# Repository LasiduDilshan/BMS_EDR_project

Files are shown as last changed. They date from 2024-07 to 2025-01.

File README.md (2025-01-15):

video1
---
Photographic_Evidence_EBMS 1-03
Photographic_Evidence_EBMS 1-04
Photographic_Evidence_EBMS 1-05
Photographic_Evidence_EBMS 1-06
Photographic_Evidence_EBMS 1-07
Photographic_Evidence_EBMS 1-08
Photographic_Evidence_EBMS 1-09
Photographic_Evidence_EBMS 1-10
Photographic_Evidence_EBMS 1-11
Photographic_Evidence_EBMS 1-12
Photographic_Evidence_EBMS 1-13
Photographic_Evidence_EBMS 1-14
Photographic_Evidence_EBMS 1-15
Photographic_Evidence_EBMS 1-16
Photographic_Evidence_EBMS 1-17
Photographic_Evidence_EBMS 1-18
Photographic_Evidence_EBMS 1-19
Path

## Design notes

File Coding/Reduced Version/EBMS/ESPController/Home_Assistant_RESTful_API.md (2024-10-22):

# EBMS v4
## Home Assistant RESTful API integration

### Secrets Configuration YAML file for Home Assistant
```
# Use this file to store secrets like usernames and passwords.
# Learn more at https://www.home-assistant.io/docs/configuration/secrets/

Ebms_api_token: XXXXXXXXXXXXXXXXXXXXXXXX
```

### Example Configuration YAML file for Home Assistant
```
# Example configuration.yaml entry for Home Assistant integration with EBMS

rest:
  - resource: http://192.168.0.70/ha
    scan_interval: 10
    timeout: 5
    method: "GET"
    headers:
      Content-Type: application/json
      ApiKey: !secret Ebms_api_token
    sensor:
      - unique_id: "Ebms.activerules"
        value_template: "{{ value_json.activerules }}"
        name: "EBMS Active rules"
        state_class: "measurement"

      - unique_id: "Ebms.chargemode"
        value_template: "{{ value_json.chgmode }}"
        name: "EBMS Charge mode"
        state_class: "measurement"

      - unique_id: "Ebms.lowest_bank_voltage"
        value_template: "{{ value_json.lowbankv }}"
        name: "EBMS Lowest bank voltage"
        unit_of_measurement: "mV"
        device_class: "voltage"

      - unique_id: "Ebms.highest_bank_voltage"
        value_template: "{{ value_json.highbankv }}"
        name: "EBMS Highest bank voltage"
        unit_of_measurement: "mV"
        device_class: "voltage"

      - unique_id: "Ebms.lowest_cell_voltage"
        value_template: "{{ value_json.lowcellv }}"
        name: "EBMS Lowest cell voltage"
        unit_of_measurement: "mV"
        device_class: "voltage"

      - unique_id: "Ebms.highest_cell_voltage"
        value_template: "{{ value_json.highcellv }}"
        name: "EBMS Highest cell voltage"
        unit_of_measurement: "mV"
        device_class: "voltage"

      - unique_id: "Ebms.highest_external_temp"
        value_template: "{{ value_json.highextt }}"
        name: "EBMS Highest cell temperature"
        unit_of_measurement: "°C"
        device_class: "temperature"

      - unique_id: "Ebms.highest_internal_temp"
        value_template: "{{ value_json.highintt }}"
        name: "EBMS Highest passive balance temperature"
        unit_of_measurement: "°C"
        device_class: "temperature"

      - unique_id: "Ebms.current"
        value_template: "{% if 'c' in value_json %}{{ value_json.c }}{% else %}0{% endif %}"
        name: "EBMS DC Current"
        unit_of_measurement: "A"
        device_class: "current"
        icon: "mdi:current-dc"

      - unique_id: "Ebms.voltage"
        value_template: "{% if 'v' in value_json %}{{ value_json.v }}{% else %}0{% endif %}"
        name: "EBMS DC voltage"
        unit_of_measurement: "V"
        device_class: "voltage"

      - unique_id: "Ebms.power"
        value_template: "{% if 'pwr' in value_json %}{{ value_json.pwr }}{% else %}0{% endif %}"
        name: "EBMS Battery power"
        unit_of_measurement: "W"
        device_class: "power"

      - unique_id: "Ebms.stateofcharge"
        value_template: "{% if 'soc' in value_json %}{{ value_json.soc }}{% else %}0{% endif %}"
        name: "EBMS State of charge"
        unit_of_measurement: "%"
        device_class: "battery"

      - unique_id: "Ebms.dynamic_charge_voltage"
        value_template: "{% if 'dyncv' in value_json %}{{ value_json.dyncv }}{% else %}0{% endif %}"
        name: "EBMS Dynamic charge voltage"
        unit_of_measurement: "V"
        device_class: "voltage"

      - unique_id: "Ebms.dynamic_charge_current"
        value_template: "{% if 'dyncc' in value_json %}{{ value_json.dyncc }}{% else %}0{% endif %}"
        name: "EBMS Dynamic charge current"
        unit_of_measurement: "A"
        device_class: "current"

    binary_sensor:
      - unique_id: "Ebms.charge_allowed"
        value_template: "{{ value_json.chgallow }}"
        name: "EBMS Battery charging allowed"

      - unique_id: "Ebms.discharge_allowed"
        value_template: "{{ value_json.dischgallow }}"
        name: "EBMS Battery discharging allowed"
```

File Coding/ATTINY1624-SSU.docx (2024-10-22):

## ADC: 12-bit

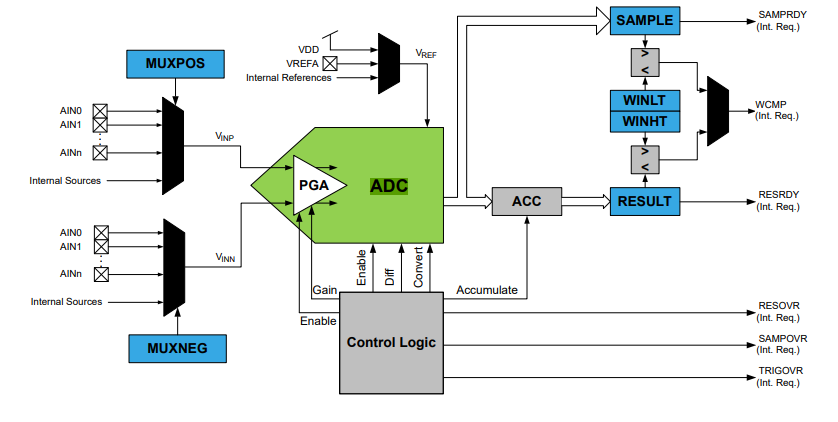
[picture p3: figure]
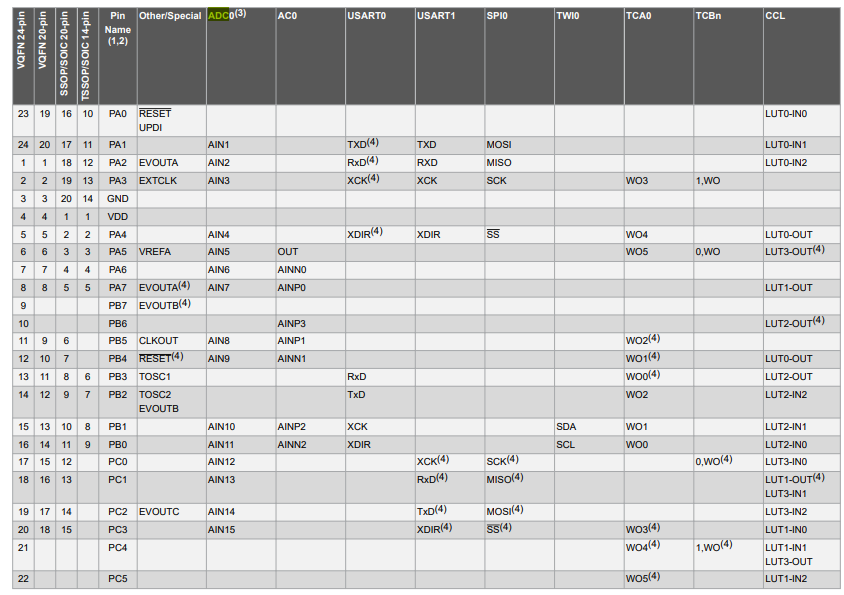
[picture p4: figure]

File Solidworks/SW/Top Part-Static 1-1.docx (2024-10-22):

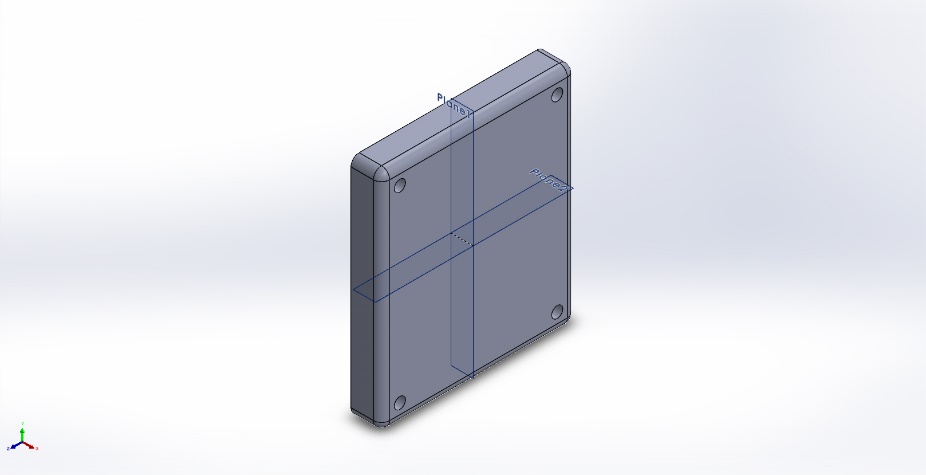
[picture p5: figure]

Simulation of Top Part

Date: Monday, May 13, 2024
Designer: Solidworks

Study name: Static 1

Analysis type: Static
Description No Data

# Assumptions

# Model Information

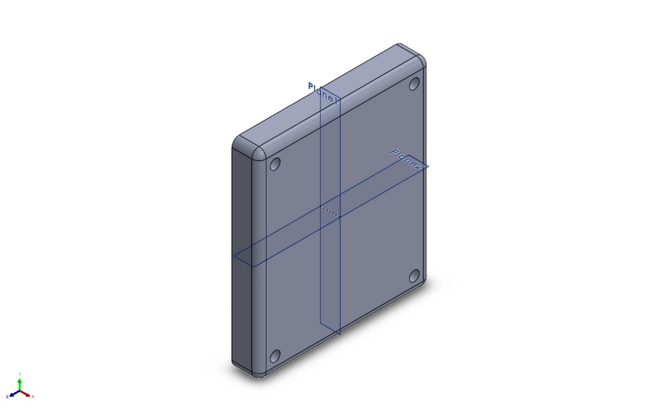
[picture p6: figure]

Model name: Top Part

Current Configuration: Default

Solid Bodies
Document Name and Reference | Treated As | Volumetric Properties | Document Path/Date Modified

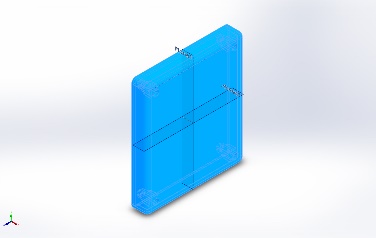
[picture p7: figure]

Mirror2 | Solid Body | Mass:4.41933e-05 kg Volume:4.41933e-05 m^3 Density:1 kg/m^3 Weight:0.000433094 N | C:\Users\senum\OneDrive\Desktop\New folder (6)\EDR\SW\Top Part.SLDPRT May 13 14:14:10 2024

# Study Properties

Study name | Static 1
Analysis type | Static
Mesh type | Solid Mesh
Thermal Effect: | On
Thermal option | Include temperature loads
Zero strain temperature | 298 Kelvin
Include fluid pressure effects from SOLIDWORKS Flow Simulation | Off
Solver type | FFEPlus
Inplane Effect: | Off
Soft Spring: | Off
Inertial Relief: | Off
Incompatible bonding options | Automatic
Large displacement | Off
Compute free body forces | On
Friction | Off
Use Adaptive Method: | Off
Result folder | SOLIDWORKS document (C:\Users\senum\OneDrive\Desktop\New folder (6)\EDR\SW)

# Units

Unit system: | SI (MKS)
Length/Displacement | mm
Temperature | Kelvin
Angular velocity | Rad/sec
Pressure/Stress | N/m^2

# Material Properties

No Data

# Loads and Fixtures

No Data

# Connector Definitions

No Data

# Contact Information

No Data

# Mesh information

No Data

# Sensor Details

No Data

# Resultant Forces

No Data

No Data

# Beams

No Data

# Study Results

No Data

# Conclusion

Analyzed with SOLIDWORKS Simulation Simulation of Top Part 16

Analyzed with SOLIDWORKS Simulation Simulation of Top Part 1

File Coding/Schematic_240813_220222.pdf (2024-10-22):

1 | 2 | 3 | 4 | 5 | 6 | 7 | 8
1 | 2 | 3 | 4 | 5 | 6 | 7 | 8

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
F Date: 2023-01-03 KiCad E.D.A. eeschema 5.1.9+dfsg1-1+deb11u1 Size: A3 | Rev: 4.6

## Id: 1/1 Title: DIYBMS ESP32 CONTROLLER

File: ControllerCircuit.sch Sheet: / Stuart Pittaway

C10
1uF

+3V3 +5V GND

C5

# 22uF GND

+3V3 10K R²⁹

R25
220R
1
2 | 3

4 U12 AQY282SX

+3.3V R²⁰ ¹M

1
2
3
4
J12 ScrewTerminal | R24

22K

R21

220R | GND GND

1
2
3
4
J7ScrewTerminal | 10K | R¹⁹ R² 2K²
1

2 3 Q4 AO3400A

GND

R1
220R

C8

100nF | C¹¹ | 1uF 51K R²⁷ | R28

22K

C9

100nF | GND
SW1 SW_Push | C⁷ | 1uF R⁷ 51K | R26
22K

+3.3V

3V3

1

IO26

10

IO27

11

IO14

12

IO12

13 GND1

14

IO13

15 SD2

16 SD3

17 CMD

18 EXT_5V

19 EN

2 GND3 20

IO23 21

IO22 22 | TXD0 23 | RXD0 24
IO21 25 | GND2 26

IO19 27

IO18 28

IO5 29 | SENSOR_VP

3

IO17 30

IO16 31

IO4 32

IO0 33

IO2 34

IO15 35 | SD1 36 | SD0 37 | CLK 38 | SENSOR_VN

4

IO34

5

IO35

6

IO32

7

IO33

8

IO25

9 U4 ESP32-DEVKITC-32D GND

+3.3V

B2 1 GND

# 2 VCCA

3 A2 4 A1 5 OE 6 VCCB

# 7 B1 8 U1 TXS0102DCU

TXD 1 | GND

## 2 VCC

3 RXD 4 VREF 5 CANL 6 CANH 7 S

8 | U7 SN65HVD1050D

1
2
3
4
5
6
7

J14 Unused header

3
1

2 D8 NUP2105LT1G

GND R⁹ | 120R | GND

1 2 JP4

OptTermination | C6

100nF

1

2 3 Q2AO3400A

1
2
3

J3 ScrewTerminal3Pin R14

560R 51K | R¹⁵ ⁵⁶⁰R | R¹³ D⁴ YELLOW LED | 1

2
3
4

# J4 ScrewTerminal

T_IRQ 1 | D/C 10 | RESET 11 | CS 12 | GND 13 | VCC | 14 T_DO 2 | T_DIN 3 | T_CS 4 | T_CLK 5 | MISO 6
LED 7 | SCK 8 | MOSI 9 | SD_SCK SD1 SD_MISO SD2 SD_MOSI SD3 SD_CS SD4

LCD1

LCD

R4
560R

R5
2K2 R16
2K2 | D5

LL4148

1

2 TX1 Transmit R3
180R

1

2 RX1 Receive

1

2 | 3 4 U2 EL3H7(B)(TA)-G

R8

120R

1
2

J10 Conn_01x02_Female

R17
220R

1
2
3

J2ScrewTerminal3Pin

1

2 | 3

4 U9 AQY282SX R18
220R

D2
LL4148

R6
120R

2 1

JP1 OptTermination

MISO VCC | 1

2 SCK 3 MOSI 4 RST 5 GND

6

J8

2x3 2.54mm IDC Connectors

+5V GND

BG

1 R

2

3 | 4
| 5

6 RGB D1

1
2
3
4

J1ScrewTerminal R

1 | RE 2 | DE 3 | D
4 | GND | 5 A

6 B

7 VCC 8 U5 SN65HVD75DR

C1

100nF | C2

# 100nF K1 SRD-05VDC-SL-C

SW2 SW_Push

1

2 3 Q1AO3400A R10

560R 51K | R¹¹ ⁵⁶⁰R | R¹² D³ YELLOW LED

C3
22uF 6.3V | C4

22uF 6.3V GND

1 VO 2 VI 3 U6 AMS1117-3.3 F1 Fuse, 1.85A

K2 SRD-05VDC-SL-C

+3V3 | GND

# +3V3 GND

C12

0.1uF-100V R30
10R

R23
10R
CS 1 Vin+ 10 | MOSI 2 Alert 3 MISO 4 SCLK 5 VS

## 6 GND

# 7 Vbus 8 Vin- 9 U8

INA229

1

2

J5 ScrewTerminal | +3.3V | GND GND | GND

1

3 | 2 Q3 AO3401A GND | GND
+3V3 | GND | GND ¹⁰K | R³¹ +3V3 GND | 10K | R³² | GND

+3V3 GND

GND

GND C¹⁴ | 100nF | GND C¹³¹uF

GND

1

2

3

4

# J9Shunt GND GND

+3.3V GND

BG

R
1

2

3

4 D6 MHPC3528CRGBCT | P10 | 13 P11 | 14 P12 | 15 P13 | 16 P14 | 17 P15 | 18 P16 | 19 P17 | 20
INT 1 | P6 | 10 P7 | 11 GND 12 VCCI 2 ADDR 21 | SCL 22 | SDA 23 | VCCP ²⁴ RESET 3 | P0 | 4 P1 | 5 P2 | 6 P3 | 7 P4 | 8 P5 | 9 U3 TCA6416APWR | GND

+3V3

+3V3 | GND
+3V3 GND | GND
GND | 10K | R²²
GND

PWR_FLAG FUSED⁵V FUSED⁵V

FUSED5V

FUSED5V

FUSED5V

FUSED5V

FUSED5V

FUSED5V

FUSED5V | FUSED⁵V

FUSED5V FUSED⁵V FUSED⁵V

FUSED5V

FUSED5V

SHUNT_CS

IO15

IO34_INPUT | VSPI_CLK

EXT_IO_A

IO0_BOOT

IO17 EXT_IO_C

EXT_IO_B

EXT_IO_A TCA⁶⁴¹⁶A_INTB

VSPI_MOSI SD_CS

TOUCH_CS

TOUCH_IRQ

RELAY4_SSR

RELAY2 RELAY1

VSPI_MISO

IO16 VSPI_MOSI VSPI_MOSI | VSPI_MISO

VSPI_MISO

VSPI_MISO

VSPI_CLK

VSPI_CLK

VSPI_CLK

VSPI_MOSI

ESP3V3 CANBUS_TX RELAY1

IO36_INPUT RESET RESET DISPLAY_DC

DISPLAY_CS CANBUS_RX RS485_ENABLE

IO39_INPUT RS485_RX | HSPI_CLK HSPI_MOSI HSPI_MISO

VSPI_CLK

VSPI_MISO
VSPI_MOSI AVRISP_RESET | SW1EXT
IO2 RELAY2 | RESET

SHUNT_IRQ

IO4

IO5

# SW1EXT SW2EXT

IO34_INPUT SW2EXT

IO26
IO25
IO33
IO32
IO35_INPUT
IO34_INPUT EXT_IO_D

RED_LED

RED_LED

SW1OUTPUT

SHUNT_CS

TCA6416A_INTB

SHUNT_IRQ

IO21
IO22

IO22

IO21 RESET | EXT_IO_D
MODULE_TX1 MODULE_RX1 | EXT_IO_C

EXT_IO_B

SW2OUTPUT BLUE_LED

DISPLAY_LED

RELAY4_SSR

SW2OUTPUT

HSPI_MOSI HSPI_MISO

VSPI_CLK

VSPI_MOSI SD_CS

SW1OUTPUT

VSPI_MISO

HSPI_CLK
IO27 BLUE_LED

i2c_SDA

i2c_SCK

i2c_SCK
i2c_SDA

i2c_SDA

IO34_INPUT

IO5 MODULE_RX1

i2c_SCK

IO0_BOOT CANBUS_TX

IO26 TOUCH_IRQ

IO17

IO16 MODULE_TX1 IO32 RS485_TX RS485_TX

IO33 SD_CS RS485_ENABLE RS485_RX

IO35_INPUT

IO39_INPUT CANBUS_RX

IO36_INPUT

TOUCH_CS

IO2 GREEN_LED | GREEN_LED

IO25 DISPLAY_DC

IO4

IO27 RELAY3_SSR

DISPLAY_CS | RELAY3_SSR

IO15 DISPLAY_LED

AVRISP_RESET | Connected to USB port
ILI9341 | MICRO SD CARD
Standard Module comms | The pins GPIO16 and GPIO17 are available for use only on the boards with

the modules ESP32-WROOM and ESP32-SOLO-1. The boards with ESP32-WROVER modules have the pins reserved for internal use.

Emergency stop button
(pulled high)

120R optional resistor
for CAN termination, CONNECTED by default Green/Red intentionally

swapped to match component + ground! (foot print wrong)

IO34 used on previous controller versions as TCA9534A_INTERRUPT_PIN Non-Commercial You may not use the material for commercial purposes.

# BATTERY+ LCSC C²⁹⁶²⁰⁹⁶

This work is licensed under a Creative Commons Attribution-NonCommercial-ShareAlike 2.0 UK: England & Wales License.

https://creativecommons.org/licenses/by-nc-sa/2.0/uk/ You are free to: Share copy and redistribute the material in any medium or format

Adapt remix, transform, and build upon the material
The licensor cannot revoke these freedoms as long as you follow the license terms.

Reverse polarity protection

CHARGER/LOAD

1=USB SERIAL
3=USB SERIAL
6=N/A
7=N/A
8=N/A
9=[NOT AVAILABE ON DEVKIT] mapped to IO16 on DEVKIT 10=[NOT AVAILABE ON DEVKIT] mapped to IO17 on DEVKIT 11=N/A
12=DISPLAY HSPI MISO / MTDI/GPIO12: internal pull-down 13=DISPLAY HSPI MOSI 14=DISPLAY HSPI CLK

16=SEE IO9
17=SEE IO10
18= VSPI_CLK (CONFIRMED)
19= VSPI_MISO (CONFIRMED) 20=N/A

23=VSPI_MOSI (CONFIRMED) 24 = N/A

28 = N/A
29 = N/A
30 = N/A
31 = N/A
37 = NOT AVAILABE ON DEVKIT 38 = NOT AVAILABE ON DEVKIT

Flyback diode calc Relay, 5VDC = 72mA 70ohm+/-10% 0.36W

LL4148, Peak Reverse Voltage 100V
Peak Fwd Surge Current 0.5A @1s, 1A@1ms Power Dissipation 500mW

120R optional resistor

for termination, CONNECTED by default Consider using part C8387 WJ15EDGRC-3.81-2P Pluggable System Terminal Block 3.81mm Power input

ONBOARD CURRENT SHUNT/MONITOR

Using 4 pin connector
to reduce part count

VBUS

i2c pull up resistors
RS-485

## CANBUS

PIN 1 is an output (received data). RS485 half duplex IC required.

LCD SCREEN = 42mA (including backlight @ 2.5mA)

## POWER CONSUMPTION

Display is only item on bus so no CS needed

Provides 5V I/O pins for external interfaces and relays, up to 10mA per port.

i2c address 0x21 (ADDR is high) | Push buttons with de-bounce

Panasonic AQY282SX

Solid State Relay 60V 500mA AC or DC | PIN MAPPING

Changes:

CANBUS_S has been removed, hard wired to low LED output resistor values changed to cater for 5v

ESP32 Strapping Pins
GPIO0, GPIO5 and GPIO15 have pull-up resistors enabled during power up.
GPIO2 and GPIO12 have pull-down resistors enabled during power up.
These pull-up and pull-down resistors can be disabled via software once the device is running.

The ESP32 will enter the serial bootloader when GPIO0 is held low on reset. Otherwise it will run the program in flash.

GPIO0 has an internal pullup resistor, so if it is left unconnected then it will pull high.

Many boards use a button marked BOOT that pulls GPIO0 low when pressed.

GPIO2 must also be either left unconnected/floating, or driven Low, in order to enter the serial bootloader. VSPI CLK=IO18 VSPI MISO=IO19 VSPI MOSI=IO23 HSPI CLK=IO14 HSPI MISO=IO12 HSPI MOSI=IO13 RESET/EN line is held high by resistor on ESP32 module/board DUAL FOOT PRINT - ONLY FIT 1 LED!

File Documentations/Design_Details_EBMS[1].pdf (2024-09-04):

EN-2160

# Electronic Design Realization

# Expandable Battery Management System

# Design Details

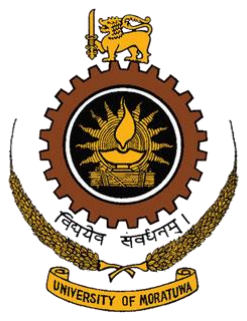
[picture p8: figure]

Name | Index Number
Dilshan N.L. Dodangoda D.K.S.J. Gunawardana W.N.M. Wathudura T.R. | 210129P 210150V 210199D 210682D

## Table of Contents

## Circuit Design Details

## Cell Module

This module is an integral component designed for the real-time monitoring of individual battery cells within a pack, each with a nominal voltage of 3.7V. This module is specifically developed to ensure the optimal performance, safety, and longevity of battery packs used in various applications, ranging from portable electronic devices to electric vehicles. The detailed functionalities, including voltage and temperature monitoring, communication via UART, and protective measures, are outlined below:

### 1. Over-voltage monitoring and voltage balancing circuit:

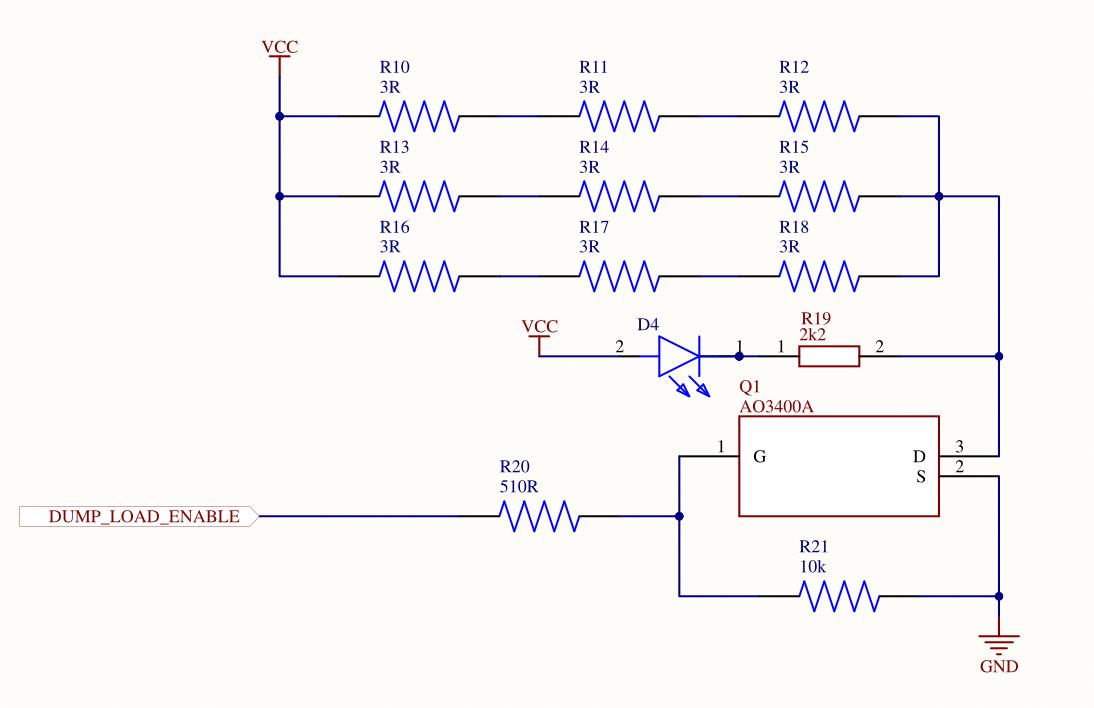
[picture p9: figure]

The battery monitoring system incorporates a sophisticated control strategy to prevent overcharging, which is critical for maintaining battery health and safety. The system utilizes a microcontroller unit (MCU) that continuously monitors the voltage levels of each battery cell within the pack. When the voltage of a cell exceeds the recommended threshold of 3.7V, indicative of potential overcharging, the MCU takes proactive measures to regulate the charge and maintain voltage stability.

❖ Activation of the Dump Load Enabler:
- Upon detection of an over-voltage condition, the MCU activates the Dump Load Enabler, which in turn controls a MOSFET. The MOSFET acts as a switch that reroutes the excess current away from the battery cell.

❖ Current Diversion Through Resistors:
- The redirected current is passed through a predefined set of resistors. These resistors are specifically chosen for their ability to handle the excess current without overheating or damage. By flowing through these resistors, the overcurrent is safely dissipated as heat, and the voltage across the battery cell is effectively lowered and stabilized at the

safe level of 3.7V.

❖ Balancing Charge Across Series-Connected Battery Packs:
- This controlled method of handling overcharge conditions not only protects individual cells but also contributes to the overall balance of charge across series-connected battery packs. By ensuring that no single cell overcharges, the system promotes uniformity in the charge state across the entire battery pack, which is essential for optimal performance and longevity of the batteries.

❖ System Benefits:
- This approach not only prevents the detrimental effects of overcharging, such as potential thermal runaway and reduced battery life but also enhances the reliability and efficiency of the battery management system. By maintaining each cell within its optimal voltage range, the system ensures that the battery pack delivers consistent performance and exhibits extended service life.

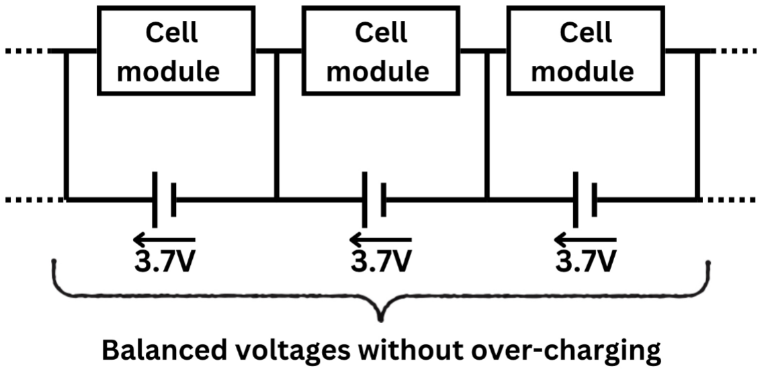
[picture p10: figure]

### 2. Temperature Sensing Circuit:

To ensure optimal performance and safety, the temperature of both the battery and the circuit within the battery management system (BMS) is meticulously monitored. This dual temperature monitoring is achieved using the CMFB103F3950FANT temperature sensor, a highly accurate and reliable component selected for its precision in thermal measurement.

❖ Sensor Specifications and Functionality:

- The CMFB103F3950FANT sensor is utilized for its exceptional responsiveness and stability across a broad range of temperatures. It is designed to provide precise temperature readings, which are critical for preventing thermal runaway and enhancing the longevity of the battery system. The sensor's ability to operate under varying environmental conditions without degradation makes it an ideal choice for the demanding requirements of battery management.

❖ Separate Monitoring of Circuit and Battery Temperatures:

In our system, separate sensors are deployed to measure.

1. The Internal Circuit Temperature: Monitoring the temperature of the electronic circuitry is essential to prevent overheating and potential damage to the BMS components. Elevated temperatures within the circuit can indicate inefficiencies or malfunctions, which may require immediate intervention.
2. The Battery Temperature: Direct measurement of the battery's temperature provides data necessary to effectively manage charging and discharging processes. It helps in maintaining the battery within safe operational limits, thus safeguarding against hazards and prolonging battery life.

Both sets of data are critical for the BMS to execute real-time decisions regarding cooling measures, charge rate adjustments, and load balancing, which are dependent on temperature fluctuations.

❖ Integration into BMS:

- Each CMFB103F3950FANT sensor is integrated into the system architecture via dedicated interfaces that relay temperature data to the central processing unit of the BMS. This integration allows for continuous monitoring and instant feedback, enabling dynamic adjustments to operational parameters in response to temperature changes detected by the sensors.
- This strategic approach to temperature monitoring underscores our commitment to system safety and efficiency, ensuring that all components operate within their thermal thresholds, thereby optimizing the performance and durability of the battery system.

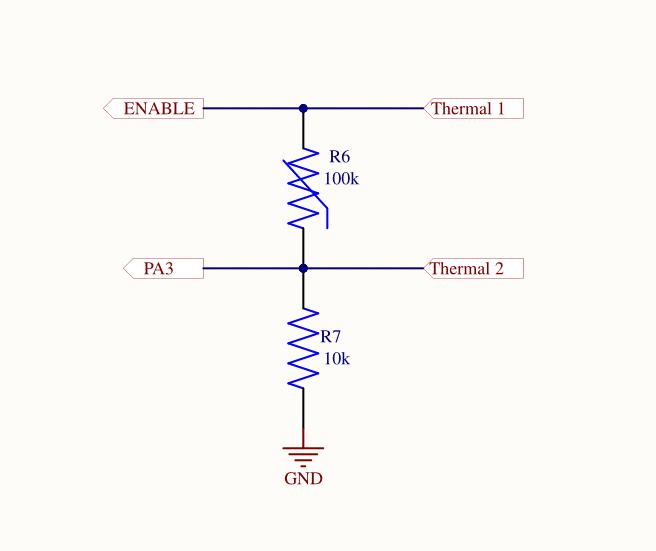
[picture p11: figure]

### 3. Micro-controller Unit:

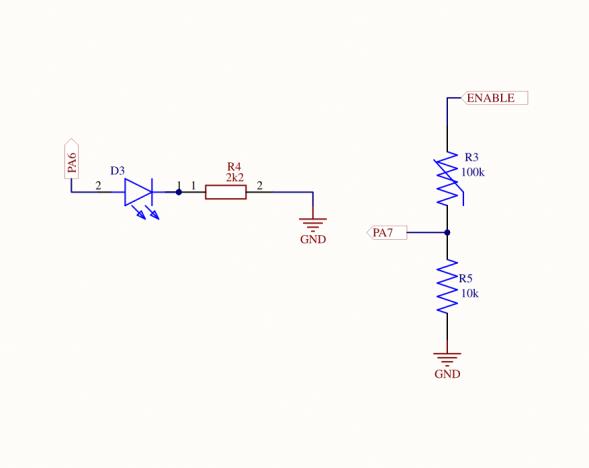
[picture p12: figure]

The battery management system employs a microcontroller to perform critical functions, including the measurement of battery cell voltages and the monitoring of temperatures using connected sensors. The microcontroller used in this system is the ATTINY1624-SSU, selected for its reliability, compact size, and capability to handle multiple inputs efficiently.

❖ Voltage and Temperature Measurement:

- The primary role of the microcontroller within the system is to continuously measure the voltage of each battery cell. This data is vital for assessing the state of charge and overall health of the battery. In parallel, the microcontroller reads inputs from temperature sensors strategically placed to monitor both the internal and ambient temperatures associated with the battery cells. These temperature readings help prevent conditions that could lead to overheating, thereby ensuring safe operation under various load conditions.

❖ Programming the Microcontroller:

- To facilitate precise control over these functions, the ATTINY1624-SSU microcontroller is programmed using a UPDI (Unified Program and Debug Interface) programmer. The UPDI programmer enables efficient uploading of necessary firmware into the microcontroller, which governs its operation. This programming method is advantageous for its simplicity and effectiveness, allowing for easy updates and debugging of the system software.
- The utilization of the UPDI programmer with the ATTINY1624-SSU microcontroller ensures that the system can be finely tuned to respond appropriately to the complex dynamics of battery management. This setup not only guarantees precision in monitoring but also provides flexibility in system configuration to accommodate future enhancements or adjustments in operational protocols.

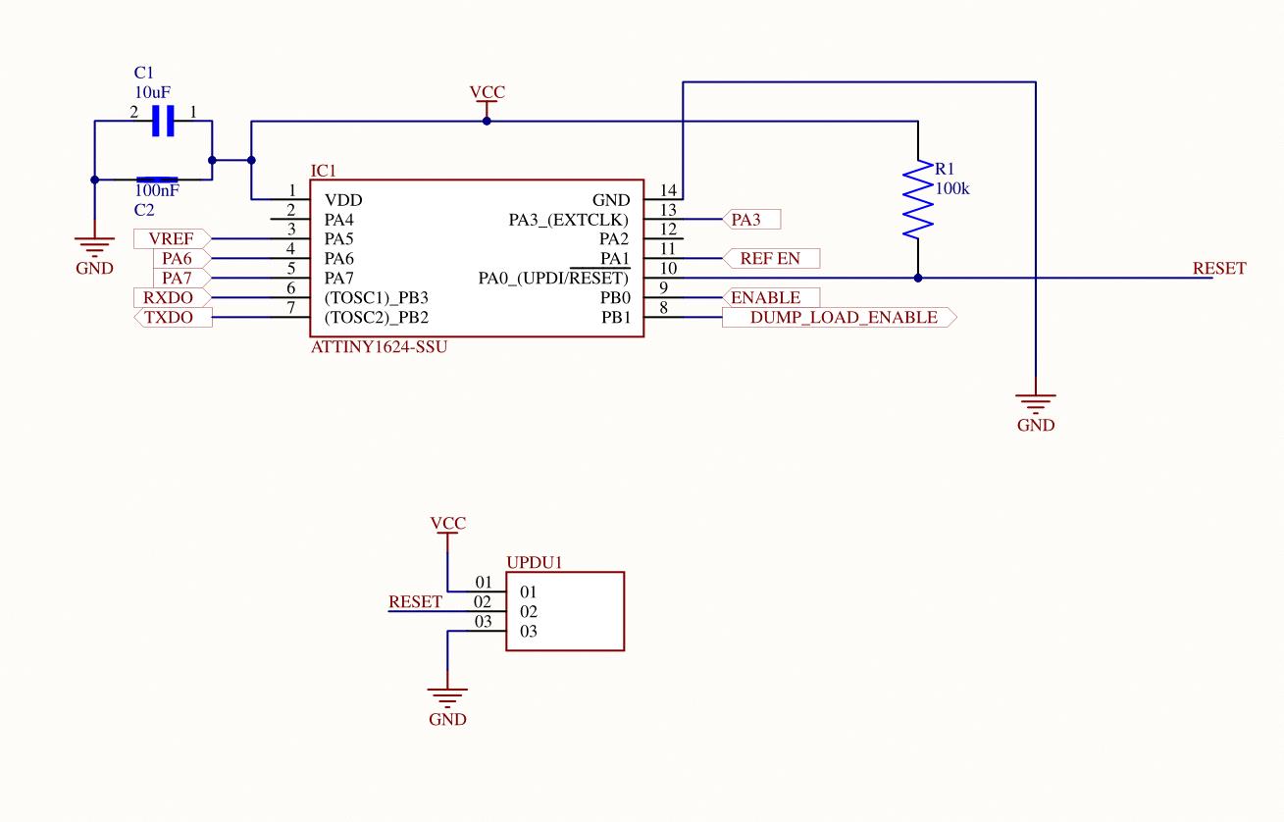
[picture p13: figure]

### 4. UART transmitter and receiver:

In the battery management system (BMS), communication and data interchange between individual battery cell modules and the main controller module are facilitated using the Universal Asynchronous Receiver/Transmitter (UART) protocol. This choice of communication standard is instrumental due to its reliability, simplicity, and effectiveness in systems requiring serial data exchange.

❖ Implementation of UART Communication

- UART protocol is utilized to establish a robust communication link within the BMS. Each battery cell module is equipped with UART capabilities, allowing it to transmit critical data such as voltage levels and temperature readings to the main controller module. This data is essential for real-time monitoring and management of the battery cells, enabling the main controller to make informed decisions regarding charge regulation, health assessment, and fault diagnostics.

❖ Importance of Series Connectivity

- The battery system is designed to be series-expandable, allowing for scalability in energy capacity and voltage levels. In such configurations, maintaining coherent and synchronized operation among multiple serially connected battery cell modules becomes crucial. The interconnection of each module in series via UART ensures seamless data transmission across the system, preserving the integrity and timing of the communicated signals. This setup not only supports the current system architecture but also accommodates future expansions with minimal adjustments.

The strategic implementation of UART interconnectivity thereby enhances the overall efficiency and reliability of the BMS, ensuring that each component within the series-connected array can communicate effectively with the main controller. This capability is vital for maintaining balanced charge cycles, monitoring state-of-health across the battery array and executing coordinated responses to operational anomalies.

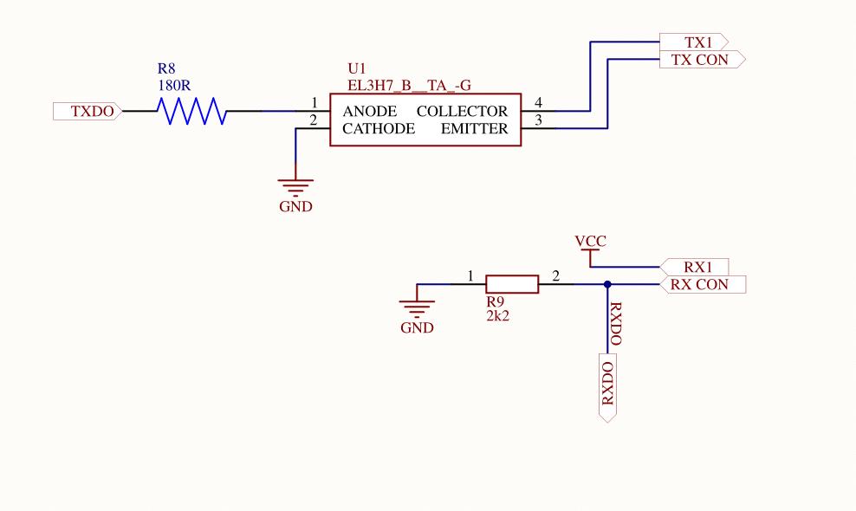
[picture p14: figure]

## Controller Module

### 1. Onboard current shunt monitor

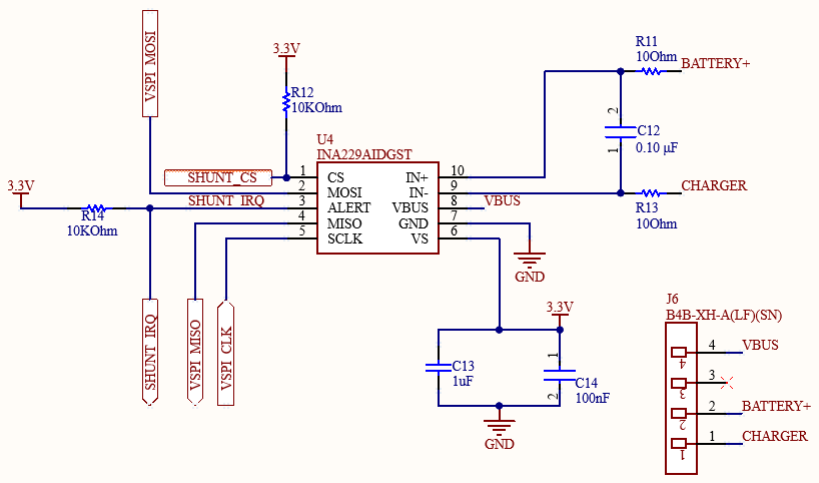
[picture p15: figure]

The onboard current shunt monitor uses the INA219, a high-side current sensor from Texas Instruments.

❖ Circuit Components:

1. INA219 (U4): This is a current shunt and power monitor with an I2C interface.
2. Shunt Resistor (R11): Placed between the load (battery) and the ground to measure the voltage drop caused by the load current.
3. Pull-up Resistors (R12, R13): Connected to the I2C lines to pull them up to 3.3V.
4. Bypass Capacitors (C11, C12, C13, C14): Used to filter noise and stabilize the power supply.
5. Connector (J6): For interfacing with the battery and charger.

❖ Circuit Description:

### 1. Current Measurement:

- The INA219 monitors the current flowing through the shunt resistor (R11).
- The voltage drop across R11 is proportional to the current passing through it.
- INA219 measures this voltage drop and, using the known resistance value of R11, calculates the current using Ohm's Law (I = V/R).

### 2. Power and Bus Voltage Measurement:

- INA219 also measures the bus voltage (VBUS), which is the voltage at the load side of the shunt resistor.
- By measuring both the current and the bus voltage, the INA219 can calculate the power consumed by the load.

### 3. I2C Communication:

- The INA219 communicates with a microcontroller (not shown in the diagram) through the I2C interface.

- The SCL (clock) and SDA (data) lines are connected to the microcontroller’s I2C bus.
- Pull-up resistors (R12, R13) are used to pull these lines up to 3.3V, ensuring proper logic levels for I2C communication.

### 4. Power Supply and Grounding:

- The circuit is powered by a 3.3V supply.
- Bypass capacitors (C11, C12, C13, C14) are placed near the power pins to filter out any high-frequency noise and stabilize the power supply to the INA219 and the I2C bus.

❖ Operation:

- When the system is powered on, the INA219 continuously monitors the voltage drop across the shunt resistor and the bus voltage.
- These measurements are sent to the microcontroller via the I2C interface.
- The microcontroller can then use these readings to monitor the current, voltage, and power consumption of the connected load, which in this case is a battery and charger system.

This circuit is designed to provide real-time monitoring of current and voltage, which is crucial for applications such as battery management systems. By integrating the INA219, the circuit offers precise measurement and easy interfacing with a microcontroller via I2C, making it suitable for the project.

### 2. Reverse polarity protection

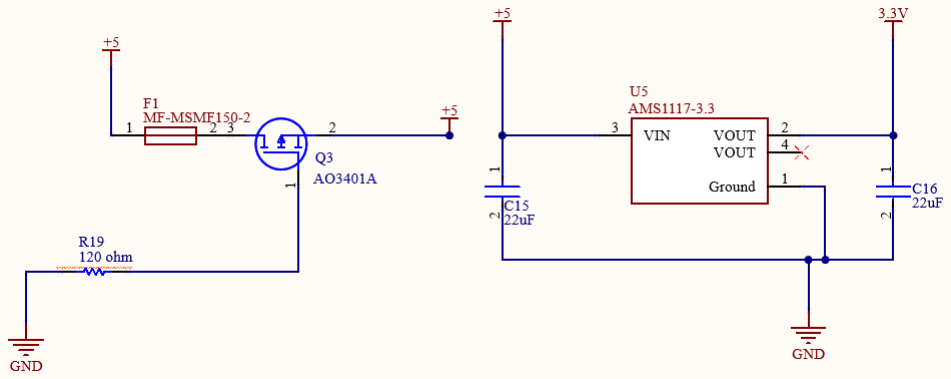
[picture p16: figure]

This circuit is designed to provide reverse polarity protection and voltage regulation for the battery management system

❖ Reverse Polarity Protection:

### 1. MOSFET (Q3 - AO3401A):

- The P-channel MOSFET (Q3) is used for reverse polarity protection.

- When the correct polarity is applied (+5V at the source, ground at the gate through R19):
- The MOSFET turns on, allowing current to flow from the source to the drain, thus providing +5V to the rest of the circuit.
- If the polarity is reversed (ground at the source, +5V at the gate through R19):
- The MOSFET remains off, preventing current from flowing and protecting the circuit from damage.

### 2. Resettable Fuse (F1 - MF-MSMF150-2):

- F1 is a resettable fuse that provides overcurrent protection.
- If the current exceeds the fuse's rating (1.5A), the fuse will trip and open the circuit, preventing damage to the components.
- Once the fault condition is removed, the fuse will reset automatically.

❖ Voltage Regulation:

### 1. Voltage Regulator (U5 - AMS1117-3.3):

- U5 is a linear voltage regulator that converts the +5V input to a stable +3.3V output.
- The VIN pin (pin 3) receives the +5V input.
- The VOUT pin (pin 2) provides the regulated +3.3V output.
- The GND pin (pin 1) is connected to ground.

### 2. Capacitors (C15 and C16 - 22uF):

- C15 and C16 are decoupling capacitors that stabilize the input and output voltages by filtering out noise and providing a smooth voltage supply.
- C15 is connected between the VIN pin and ground.
- C16 is connected between the VOUT pin and ground.

Overall Functionality:

- The circuit ensures that power is only delivered to the battery management system if the input voltage is correctly polarized.
- It protects the system from reverse polarity and overcurrent conditions.
- It provides a stable +3.3V output from a +5V input, suitable for powering components that require a lower voltage.

By incorporating these components, the circuit enhances the reliability and safety of the battery management system.

### 3. IO Expander

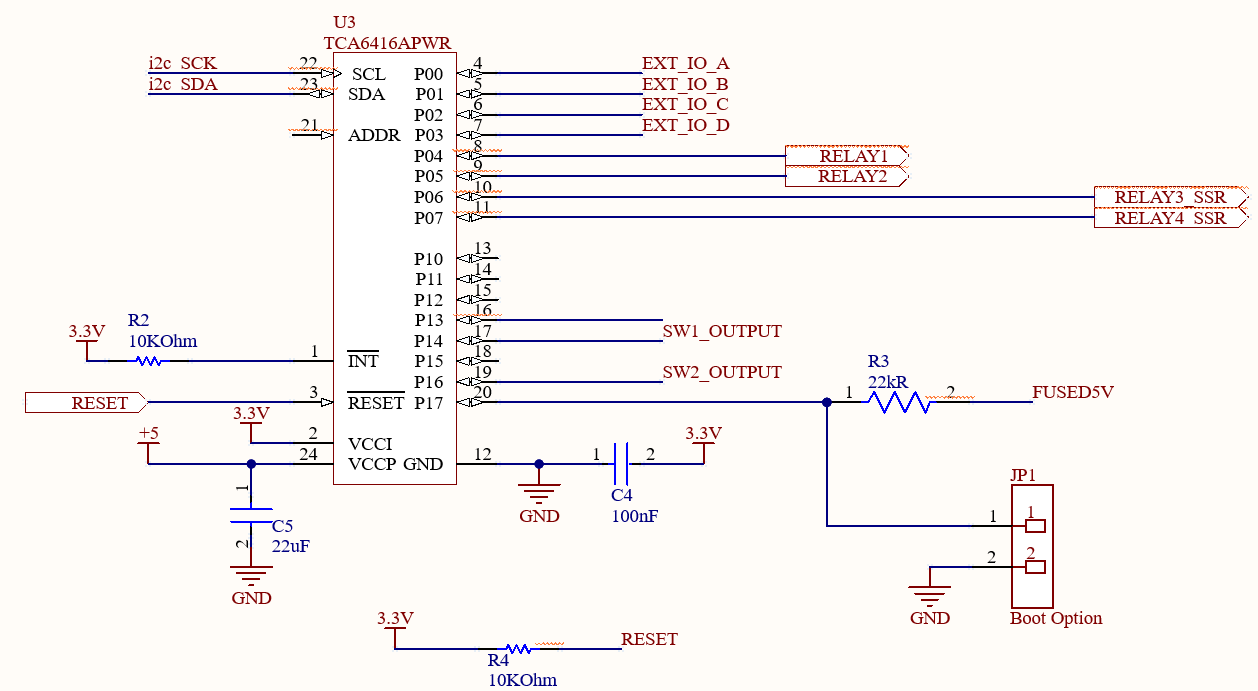
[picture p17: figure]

This schematic illustrates the integration of TCA6416A I/O expander within the battery management system (BMS).

❖ Functional Overview:

### 1. I2C Communication:

- Pins 22 (SCL) and 23 (SDA): These pins facilitate communication with the microcontroller via the I2C bus, allowing the microcontroller to control and monitor the states of the GPIO pins on the I/O expander.

### 2. General Purpose Input/Output (GPIO) Expansion:

- Pins P00 – P17 The TCA6416A provides 16 GPIO pins, which can be configured individually as either inputs or outputs. These pins are connected to various external components:
- EXT_IO_A to EXT_IO_D (Pins 4-7): General-purpose external I/O lines.
- RELAY1 and RELAY2 (Pins 8 and 9): Control signals for mechanical relays, used to switch high power loads or other circuits.
- RELAY3_SSR and RELAY4_SSR (Pins 10 and 11): Control signals for solid-state relays (SSR), offering faster switching and longer life compared to mechanical relays.
- SW1_OUTPUT and SW2_OUTPUT (Pins 18 and 19): Output signals to control or indicate the status of switches, for user inputs or control signals for other devices.

### 3. Power and Ground Connections:

- VCCI (Pin 24): 3.3V supply voltage for the device’s logic.
- VCCP (Pin 2): 5V supply voltage, likely used for driving the external components connected to the GPIOs.
- GND (Pin 1 and others): Common ground reference for the circuit.
- Capacitors:
- C4 (100nF): Provides noise filtering and stabilization for the power supply.
- C5 (22uF): Larger decoupling capacitor to smooth out voltage variations and provide

stable power.

### 4. Control and Configuration:

- RESET (Pin 3): This pin is used to reset the I/O expander. The reset circuit includes a 10kΩ pull-up resistor (R2) and a RESET switch, allowing manual reset of the device.
- INT (Pin 15): The interrupt pin can be used to alert the microcontroller of any changes in the state of the input pins, enabling efficient event-driven programming.

### 5. Boot Option (JP1):

- JP1 Connector: Provides a jumper configuration for boot options, which might be used to select different operational modes or configurations for the system.
- R3 (22kΩ resistor): Pull-up resistor associated with the boot option selection, ensuring a defined logic level when the jumper is not connected.

❖ Overall Functionality:

The TCA6416A I/O expander significantly increases the I/O capacity of the BMS, enabling it to interface with a variety of external components such as relays, switches, and other digital inputs/outputs. This extension of I/O capability allows the BMS to monitor and control more aspects of the battery system, enhancing its functionality and flexibility. Through the I2C interface, the microcontroller can easily manage these additional I/O points, making the system more scalable and adaptable to complex requirements.

### 4. Standard module communication circuit

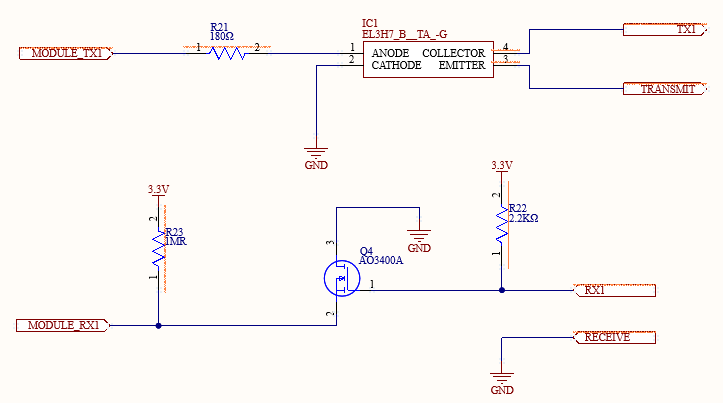
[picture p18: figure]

This schematic illustrates the standard module communication circuit in the BMS. The circuit facilitates the communication between the BMS and external modules, enabling data transmission and reception.

❖ Key Components and Their Functionality:

### 1. Optocoupler (IC1 - EL3H7):

- Pins 1 (Anode) and 2 (Cathode): The input side of the optocoupler, where the signal from the BMS is applied. The optocoupler isolates the transmitting circuit electrically from the receiving circuit.

- Pins 3 (Collector) and 4 (Emitter): The output side of the optocoupler, where the isolated signal is transmitted to the external module.
- Function: The optocoupler provides galvanic isolation, protecting the BMS from voltage spikes and noise that might originate from the external modules. It ensures that the signal integrity is maintained across the isolation barrier.

### 2. Resistors:

- R21 (180Ω): Limits the current through the optocoupler when transmitting data from the BMS (TXI).
- R22 (22kΩ): Pull-down resistor ensuring that the RXI line remains at a known logic level when the transistor is not conducting.
- R23 (1MΩ): Pull-up resistor for the gate of the MOSFET, ensuring it remains off when not driven by the optocoupler.
- Function: These resistors are critical for current limiting, pulling voltages to defined levels, and ensuring stable operation of the circuit components.

### 3. MOSFET (Q4 - AO3400A):

Acts as a switch that is controlled by the optocoupler. When the optocoupler is activated by the BMS transmit signal, the MOSFET allows current to flow, transmitting the signal to the receiving module.

### 4. Communication Lines:

- MODULE TXI: Input from the BMS transmitting module.
- TXI: Transmit line to the external module after passing through the optocoupler.
- MODULE RXI: Input from the receiving module to the BMS.
- RXI: Receive line from the external module, controlled by the MOSFET.
- TRANSMIT and RECEIVE: External connectors for communication with external modules.

This circuit provides a robust and isolated communication interface for the battery management system, ensuring safe and reliable data exchange between the BMS and external modules. The use of an optocoupler ensures electrical isolation, protecting the BMS from potential electrical disturbances, while the MOSFET facilitates controlled signal reception. The resistors ensure proper current flow and voltage levels for stable operation.

## Enclosure Design Details

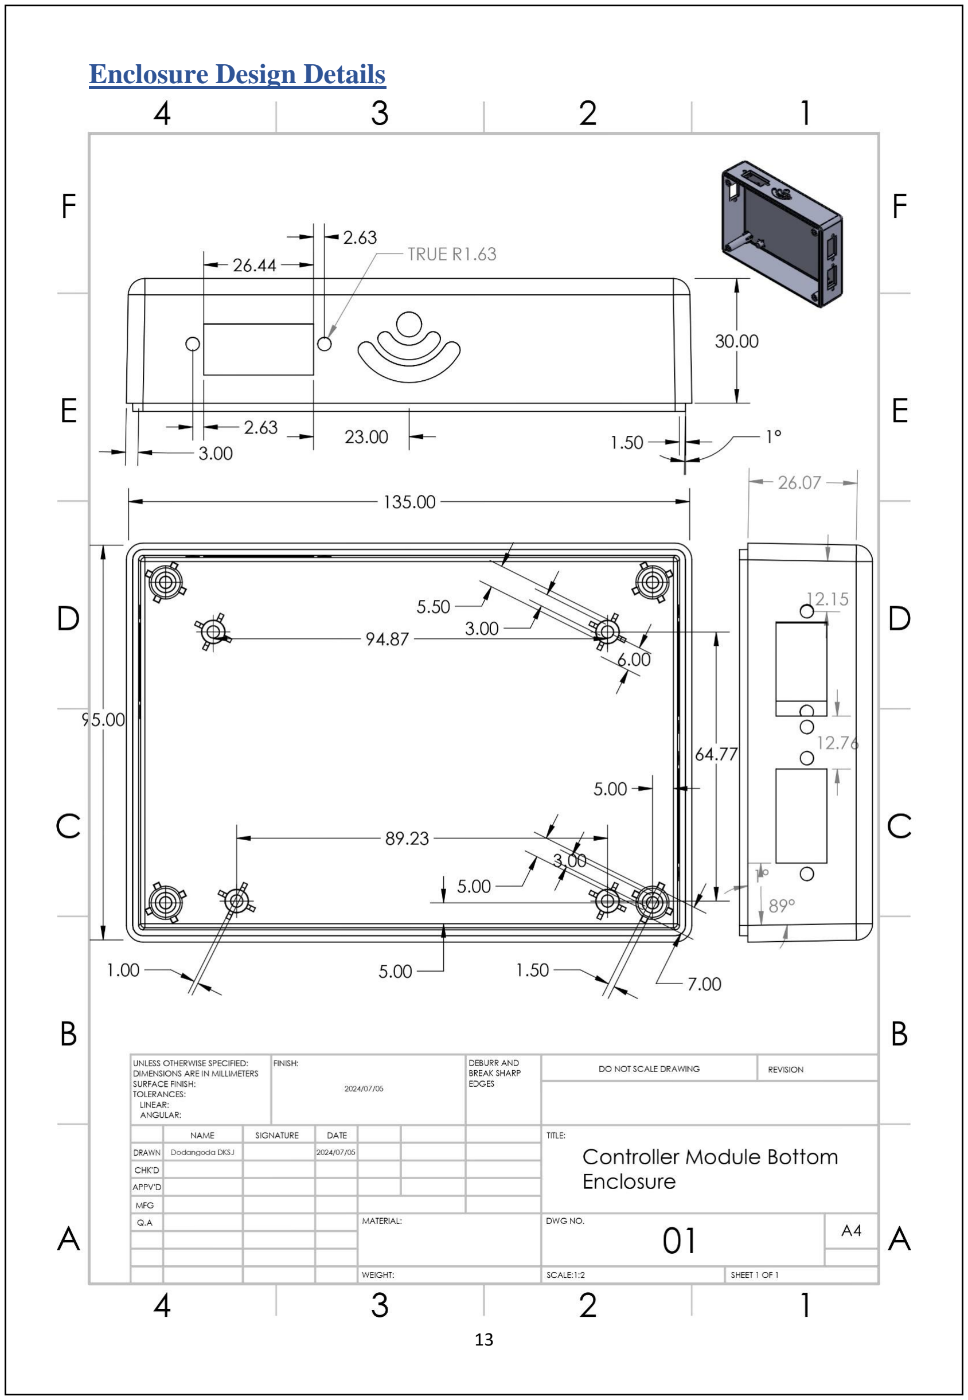
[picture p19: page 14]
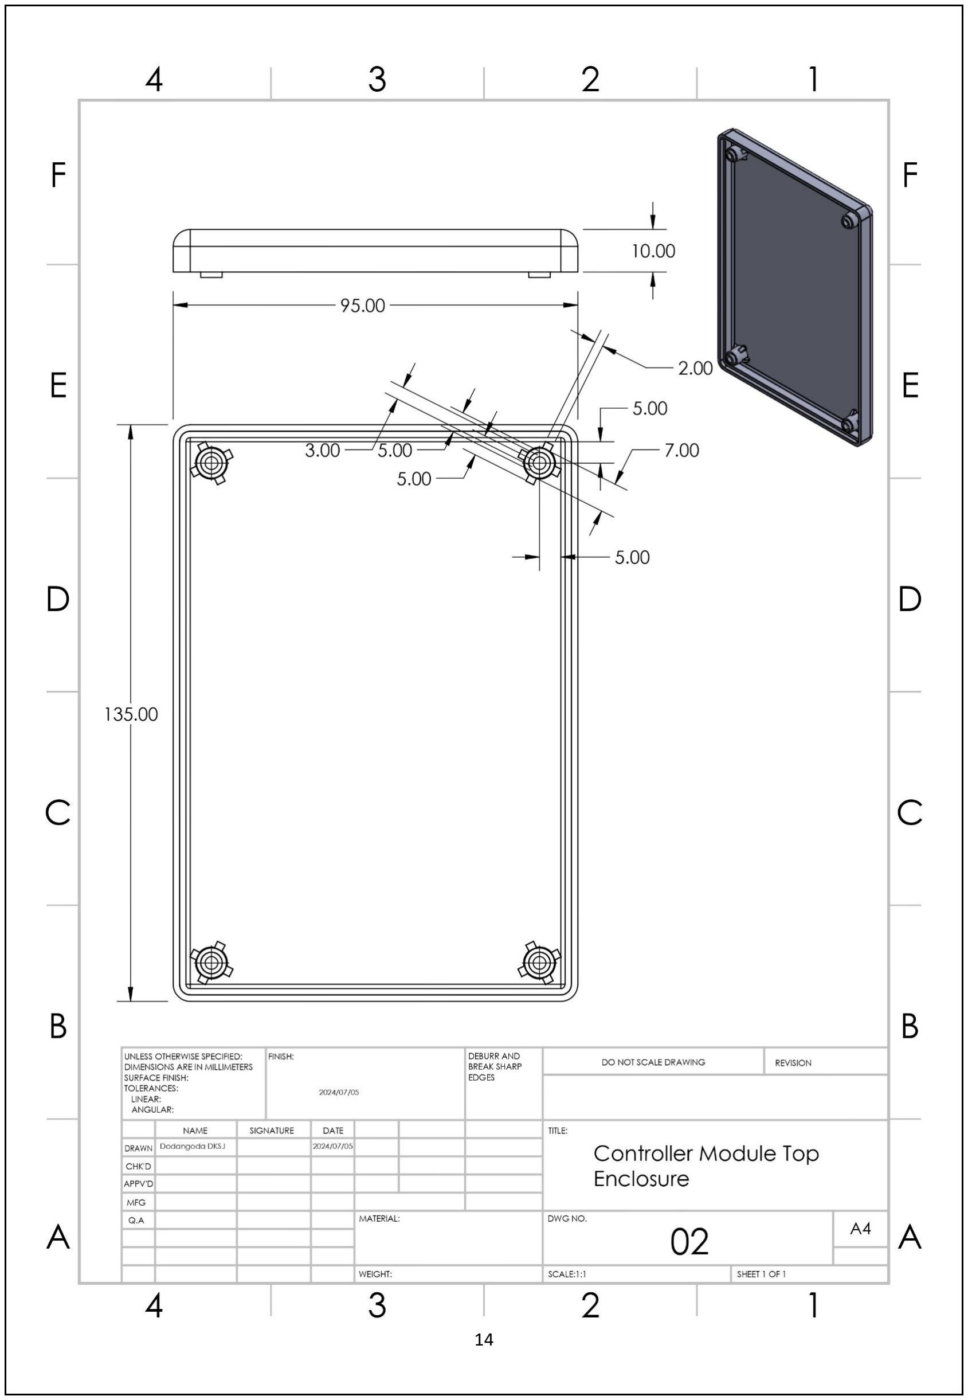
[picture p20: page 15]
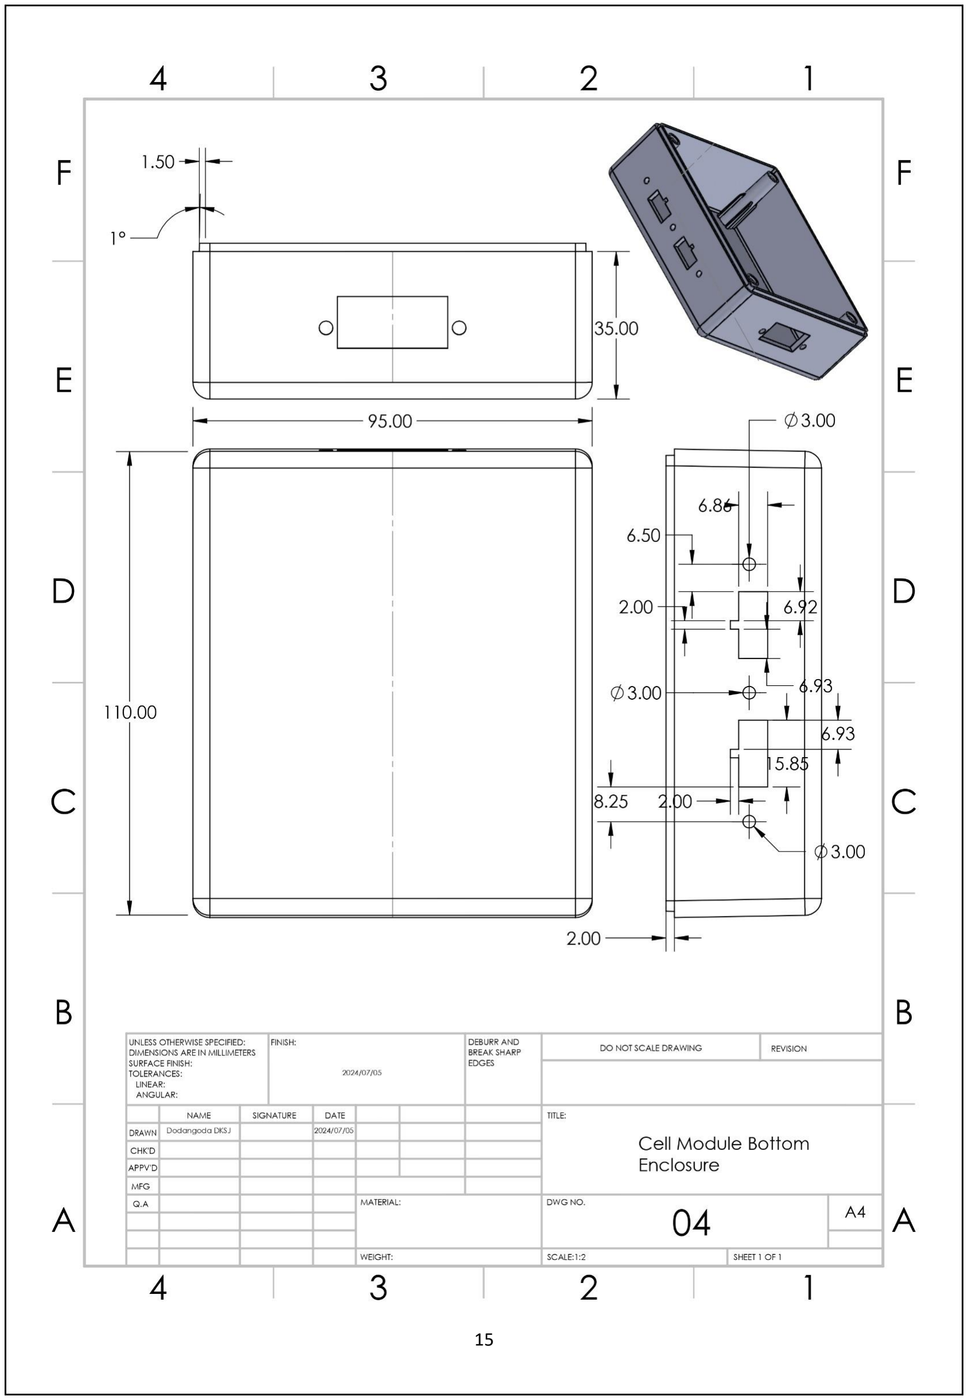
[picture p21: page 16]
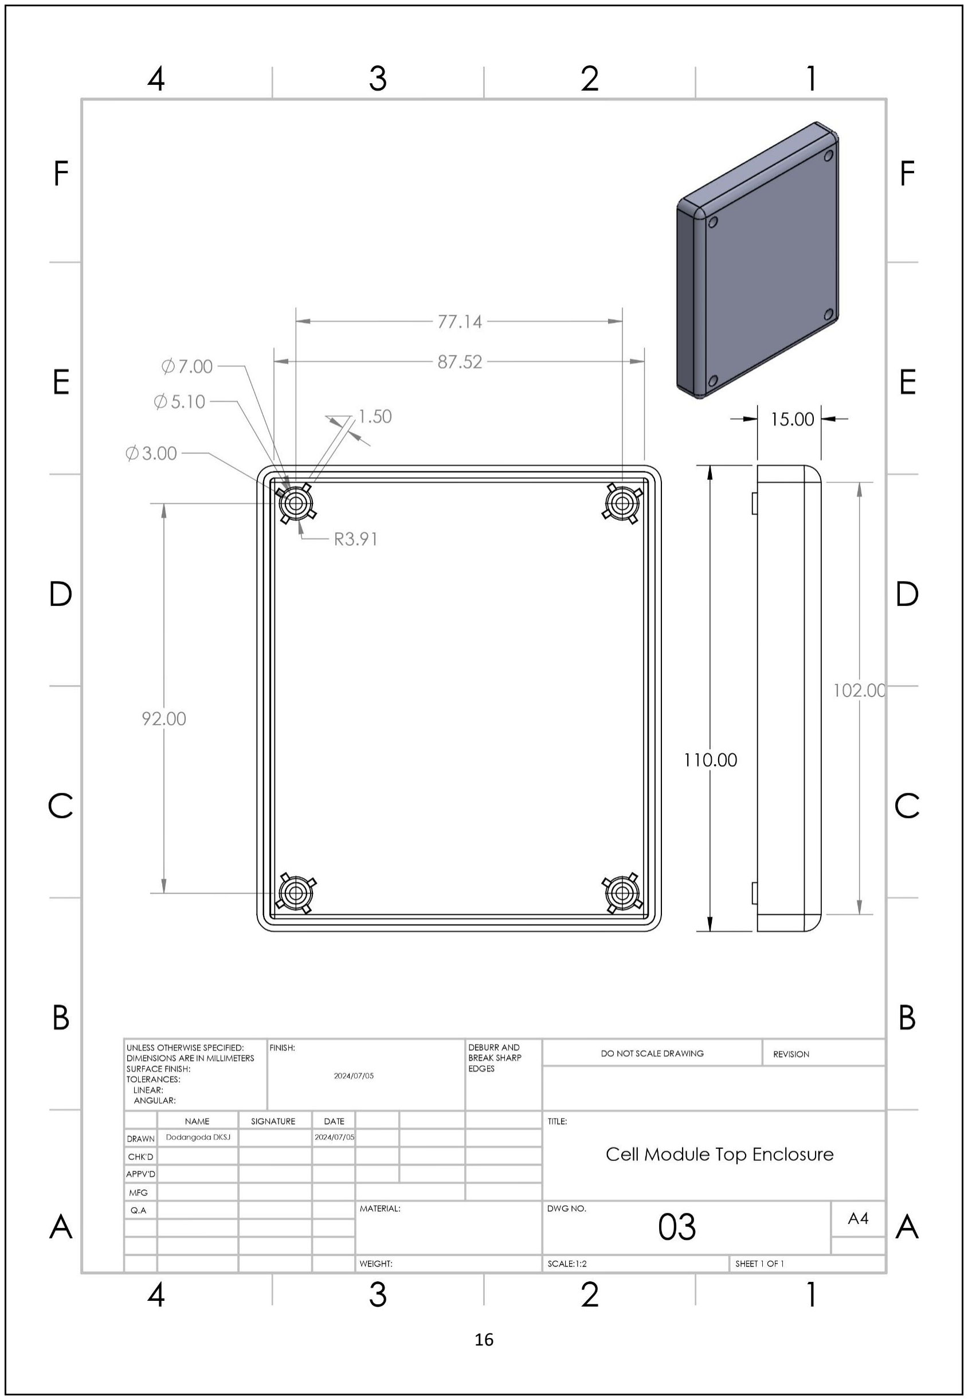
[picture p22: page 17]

## Programming

❖ In this section we will focus on programming of the ATTINY1624-SSU Microcontroller unit manufactured by Microchip.

❖ AVR Port Manipulation method was used while Microchip Studio was used as the programming software.

❖ The following sections from the datasheet were used for the correct implementation of the code.

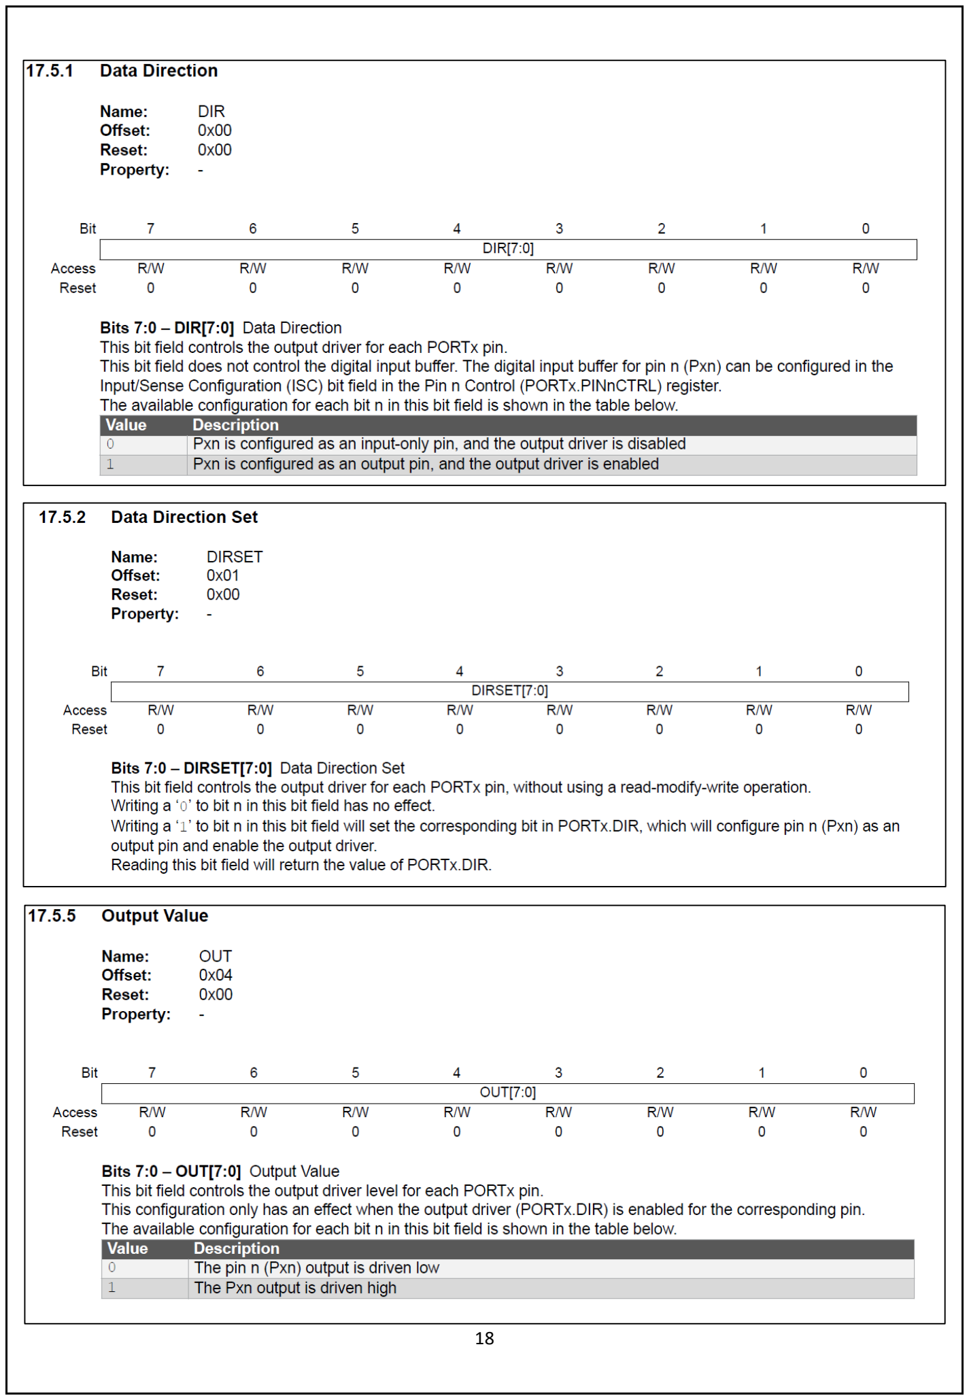
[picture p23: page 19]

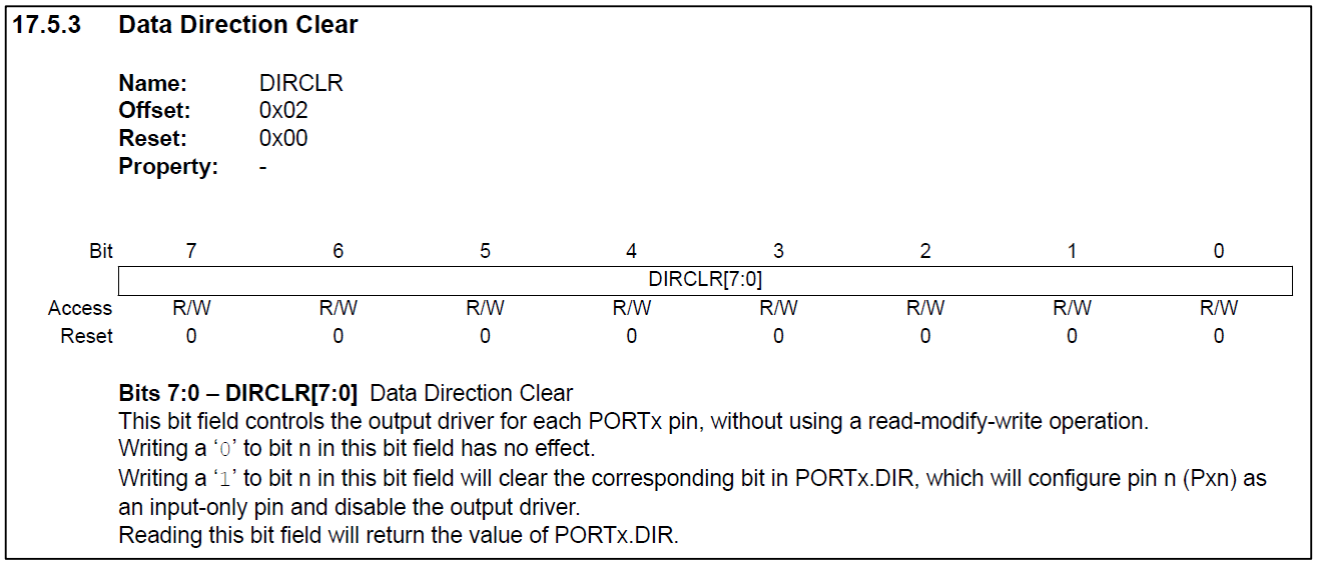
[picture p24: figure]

❖ For more details:

https://www.alldatasheet.com/datasheet-pdf/pdf/1425243/MICROCHIP/ATTINY1624-SSU.html (https://www.alldatasheet.com/datasheet-pdf/pdf/1425243/MICROCHIP/ATTINY1624-SSU.html)

❖ The “diybms_tinyAVR2.cpp” file provides a comprehensive description and implementation of various hardware-related functionalities critical for the Battery Management System (BMS) on the tinyAVR2 microcontroller platform.

1. Pin Configurations: Detailed setup of the microcontroller's pins, specifying their roles (input/output) and functionalities. This ensures that each pin is correctly assigned for its intended purpose.
2. ADC Configurations: Configuration of the Analog-to-Digital Converter (ADC) settings to facilitate accurate analog signal readings. This involves setting up the ADC resolution, reference voltage, and input channels to read various analog parameters.
3. ADC Readings: Implementation of routines to perform ADC conversions and retrieve the analog values. These readings are crucial for monitoring the battery's voltage and temperature.
4. LED Functionalities: Management of LED indicators to provide visual feedback on the system's status. This includes configuring the pins connected to the LEDs and controlling their behavior (e.g., blinking patterns) to indicate different operating conditions, such as normal operation, warnings, or errors.

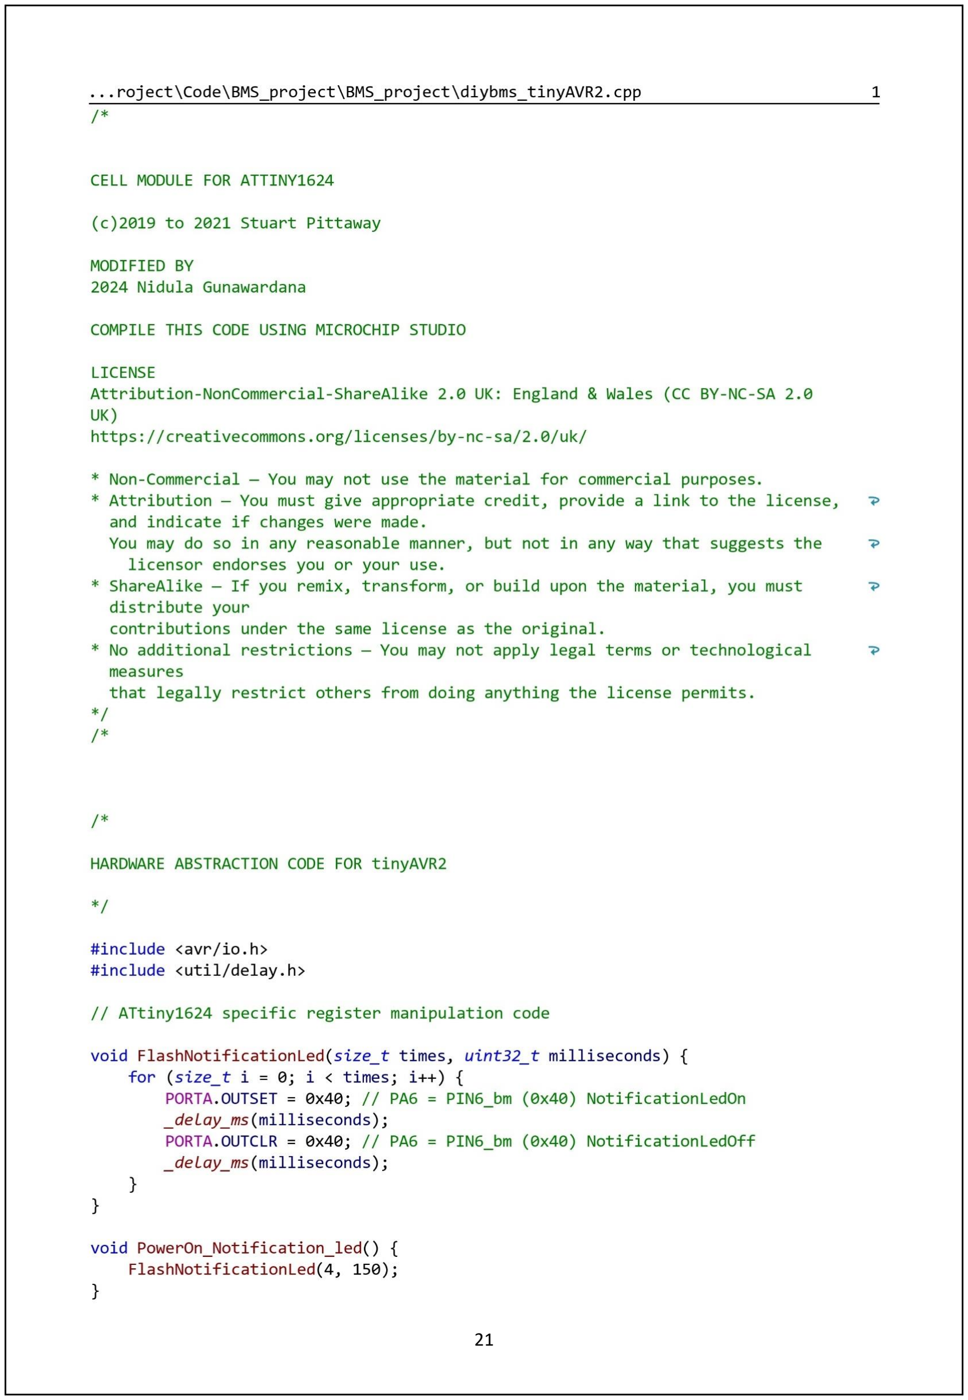
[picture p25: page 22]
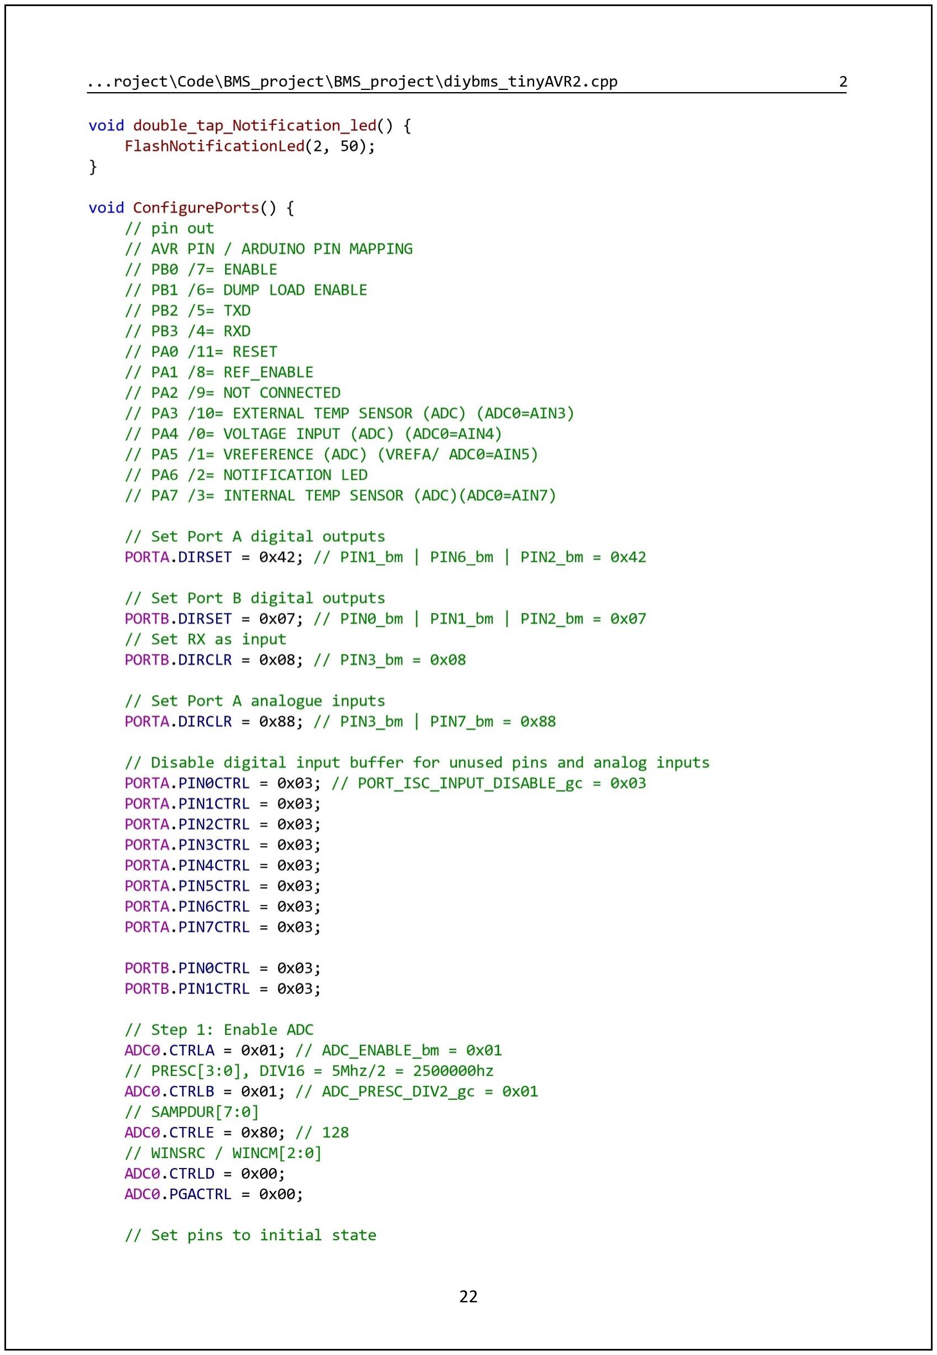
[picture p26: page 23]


❖ The main.cpp file in this project serves as the core component responsible for executing critical monitoring and control functionalities. Its primary tasks include:

- Battery Voltage Monitoring: Continuously measures the battery voltage to ensure it remains within safe and optimal operating ranges. This is crucial for maintaining the health and longevity of the battery, as well as ensuring the reliability of the device it powers.
- Temperature Monitoring: Tracks the temperature of the battery and internal circuits. This is essential for preventing overheating, which could lead to component damage or failure, and for optimizing performance by maintaining an ideal temperature range.
- PID Controller Implementation: Utilizes a Proportional-Integral-Derivative (PID) controller to regulate both the battery voltage and the temperatures of the battery and internal circuits.

❖ The PID controller adjusts the system's operational parameters in real-time to maintain these values within their desired setpoints. It does this by:

- Proportional Control: Responding to the current error between the desired setpoint and the actual value.
- Integral Control: Addressing the accumulation of past errors to eliminate steady-state offset.
- Derivative Control: Predicting future errors based on the current rate of change, helping to dampen oscillations and improve stability.

❖ By integrating these functionalities, the main.cpp file ensures robust and efficient management of the system's power and thermal conditions, thereby enhancing the reliability and performance of the overall device.


❖ We hereby declare that Arduino was not used for programming the microcontroller from the beginning.

## Daily Log Entries

No | Date | Log Entry
1 | 01/02/2024 | ❖ Evaluated problems in the industry & selected the project. ❖ Created a preliminary project plan outlining resources, phases, tasks, and timeline. ❖ Discussed potential design approaches and technical challenges.
2 | 07/02/2024 | ❖ Read articles, papers related to BMS design. ❖ Made sure everyone had a good understanding about the project. ❖ Planned next steps.
3 | 18/02/2024 | ❖ Created the stake holder map. ❖ Identified the users of a BMS. ❖ Identified the needs of the users. ❖ Planned the strategies to fulfill these needs. ❖ Planned next steps.
4 | 22/02/2024 | ❖ Did a thorough analysis of how we are going to fulfill these needs. ❖ Identified different sub systems required to fulfill the above needs.
5 | 6/03/2024 | ❖ Conceptual designs. ❖ Created the block diagram view of the project. ❖ Created possible conceptual designs as sketches.
6 | 11/03/2024 | ❖ Started Circuit Design & Enclosure design. • Began designing the circuit layout. • Sketched initial circuit layouts on paper, outlining potential power and signal flow pathways. • Discussed the use of protection circuits. • Considered possible safety mechanisms. • Sketched a detailed view of the enclosure.
7 | 13/03/2024 | ❖ Continued Circuit Design & Enclosure design. • Continued refining the circuit design. • Incorporated microcontroller and communication interfaces. • Drew rough schematics of the circuit layout. • Continued sketching the enclosure.

8 | 14/03/2024 | ❖ Schematic Design & Enclosure design • Started creating digital schematics. • Focused on organizing the schematics logically. • Used hierarchical schematic design procedure. • Started designing the enclosure on SolidWorks.
9 | 15/03/2024 | ❖ Schematic Design & Enclosure design. • Continued building and refining the schematic design, making sure all key components and connections are represented. • Conducted a review with the team to check for consistency and completeness. • Made necessary adjustments. ❖ Continued designing the enclosure on SolidWorks.
10 | 20/03/2024 | ❖ PCB Layout & Enclosure design • Transitioned from schematic design to PCB layout, starting with component placement on the board. • Focused on optimal placement for signal integrity and power management. • Considered size constraints and the placement of key interfaces. ❖ Continued designing the enclosure on SolidWorks.
11 | 21/03/2024 | ❖ PCB Layout & Enclosure design • Continued routing connections between components. • Ensured proper trace widths and clearance for power handling and signal lines. ❖ Continued designing the enclosure on SolidWorks.
12 | 24/03/2024 | ❖ PCB Layout & Enclosure design • Conducted a detailed design review, checking the PCB layout against the schematic and requirements. • Made final adjustments based on review feedback.
13 | 25/03/2024 | ❖ Enclosure Design • Completed the design of the enclosure. • Created the mold for the enclosure.
14 | 10/04/2024 | ❖ Ordered necessary components.

15 | 15/04/2024 | ❖ PCB Production. • Submitted finalized PCB design files to a manufacturer for production.
16 | 17/04/2024 | ❖ Programming the Microcontroller. • Identified the main functions which should be performed by the microcontroller. • Selected suitable software for programming.
17 | 19/04/2024 | ❖ Started coding and it was continued parallelly with the following tasks.
18 | 23/04/2024 | ❖ PCB arrived.
19 | 25/04/2024 | ❖ Components arrived. ❖ Continued programming.
20 | 29/04/2024 | ❖ PCB Assembly & Soldering - Part 1 • Began assembling components on the PCB according to the design. • Carefully placed and soldered each component, starting with smaller ones and progressing to larger ones.
21 | 30/04/2024 | ❖ PCB Assembly & Soldering - Part 2 • Continued assembly and soldering.
22 | 31/04/2024 | ❖ PCB Assembly & Soldering - Part 3 • Completed assembly and soldering of the PCB.
23 | 06/05/2024 | ❖ Initial Power-Up & Testing • Conducted the initial power-up tests for the BMS. • Checked for any short circuits, incorrect connections, and component functionality.
24 | 07/05/2024 | ❖ Testing & Troubleshooting - Part 1 • Performed tests, including voltage, current, and temperature measurements.

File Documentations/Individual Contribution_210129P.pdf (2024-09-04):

EN-2160

# Electronic Design Realization

# Expandable Battery Management System

# Individual Contribution


210129P
Dilshan N.L.

## My Contribution to the Battery Management System (BMS) Project

As a key member of the BMS project team, I focused on designing and developing the battery cell module Printed Circuit Board (PCB). This module is crucial for real-time monitoring and management of individual battery cells (3.7V nominal voltage) in various applications, optimizing performance, safety, and lifespan.

Key Contributions:

1. Circuit Design: I meticulously designed the cell module circuit with advanced features for over-voltage monitoring and voltage balancing. This included creating a control strategy to prevent overcharging, critical for battery health and safety. A microcontroller unit (MCU) continuously monitors cell voltages. Upon over-voltage detection, the MCU activates a Dump Load Enabler to control a MOSFET, safely dissipating excess current through resistors as heat, stabilizing cell voltage.
2. Schematic Design: I created detailed schematics for the cell module, outlining component connections. This blueprint ensures all elements function together. The design incorporates resistors, MOSFETs, and the MCU for efficient over-voltage protection and voltage balancing.
3. PCB Layout Design: I designed the cell module PCB layout to accommodate five modules, allowing for simultaneous evaluation of five battery cells. This space-optimized design ensures reliable connectivity and integration of all components. The layout facilitates effective heat dissipation and minimizes interference, contributing to BMS stability and performance.
4. Cell Module Programming: I actively participated in programming the cell module for intercommunication and data transmission. This involved developing firmware for the ATTINY1624-SSU microcontroller to handle temperature, voltage, and current monitoring. The program facilitates communication between modules using the UART protocol for real-time data transmission to the main controller.
5. Enclosure Design: I participated in designing the enclosure for mounting the cell modules using SolidWorks. This moldable enclosure securely houses the PCB and provides environmental protection. The design ensures ease of installation and maintenance, contributing to overall BMS durability and functionality.
6. Conceptual BMS Design: Beyond the cell module, I significantly contributed to the overall BMS conceptual design. This involved outlining the system architecture and defining interactions between components and modules. My contributions ensured a cohesive integration of monitoring and control mechanisms across the entire battery pack, enhancing system scalability, reliability, and efficiency.

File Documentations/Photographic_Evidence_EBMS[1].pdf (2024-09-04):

EN-2160

# Electronic Design Realization

# Expandable Battery Management System

# Photographic Evidence


Name | Index Number
Dilshan N.L. Dodangoda D.K.S.J. Gunawardana W.N.M. Wathudura T.R. | 210129P 210150V 210199D 210682D

## Table of Contents

## 1. Photographs of the Bare PCB

## Main Controller


## Cell Module


## 2. Photographs of the Soldered PCB

## Main Controller


## Cell Module



## 3. Photographs of the physically built enclosure

## Enclosure for the Cell Module


## Enclosure for the Main Controller


## 4. Photographs of System Integration



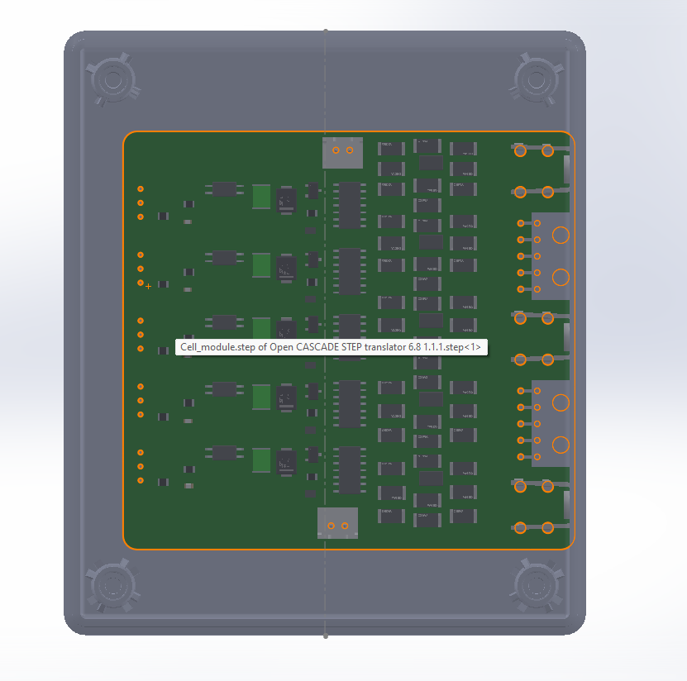
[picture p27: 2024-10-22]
Solidworks/SW/cell module/Screenshot 2024-05-13 142034.png

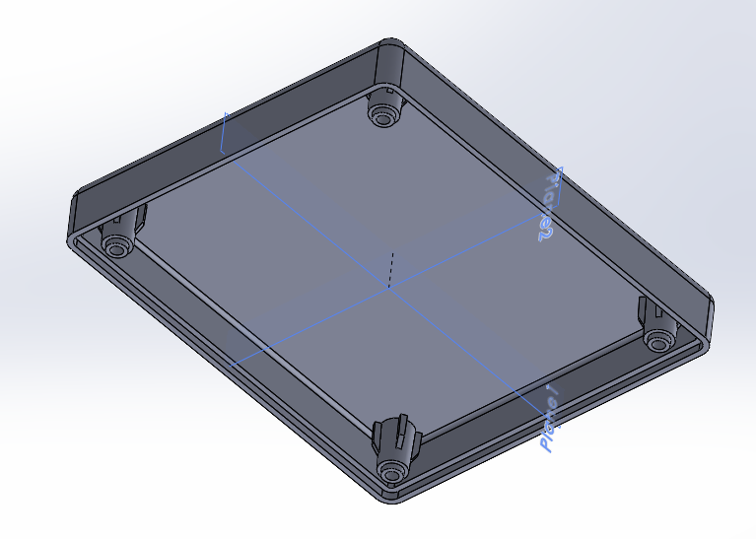
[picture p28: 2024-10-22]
Solidworks/SW/cell module/Screenshot 2024-05-13 142230.png

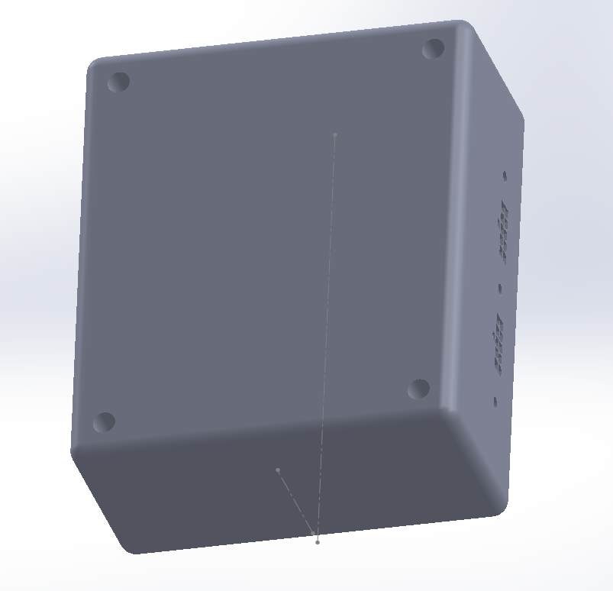
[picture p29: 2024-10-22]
Solidworks/SW/cell module/Screenshot 2024-05-13 142106.png

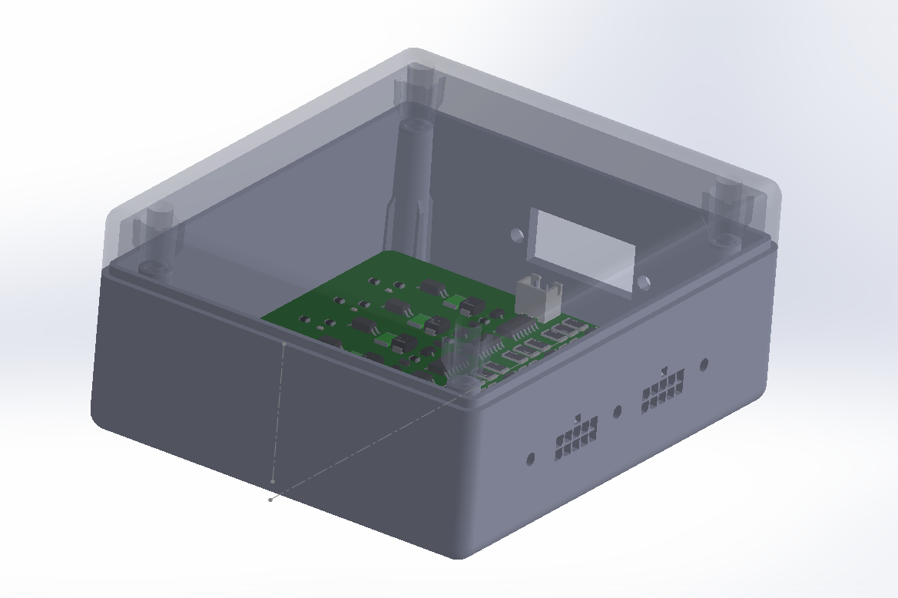
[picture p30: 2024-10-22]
Solidworks/SW/cell module/Screenshot 2024-05-13 142026.png

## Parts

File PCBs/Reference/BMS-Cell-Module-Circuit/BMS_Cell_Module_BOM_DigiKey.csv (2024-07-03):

Manufacturer Part Number | Manufacturer | Digi-Key Part Number | Customer Reference | Reference Designator | Packaging | Part Status | Quantity | Unit Price | Extended Price | Quantity Available | Mfg Std Lead Time | Description | RoHS Status | Lead Free Status | REACH Status | US Tariff Status
CL21B225KPFNNNE | Samsung Electro-Mechanics | 1276-1188-1-ND |  | C1,C2 | Cut Tape (CT) | Active | 2 | 0.21000 | AU$0.42 | 235036 | Not Available | CAP CER 2.2UF 10V X7R 0805 | RoHS Compliant | Lead free | REACH Unaffected | Tariff Eligible
CL21B104MBCNNNC | Samsung Electro-Mechanics | 1276-2450-1-ND |  | C3,C4,C5 | Cut Tape (CT) | Active | 3 | 0.15000 | AU$0.45 | 952896 | Not Available | CAP CER 0.1UF 50V X7R 0805 | RoHS Compliant | Lead free | REACH Unaffected
CL21B224KBFNNNG | Samsung Electro-Mechanics | 1276-6478-1-ND |  | C6 | Cut Tape (CT) | Active | 1 | 0.15000 | AU$0.15 | 144430 | Not Available | CAP CER 0.22UF 50V X7R 0805 | RoHS Compliant | Lead free | REACH Unaffected | Tariff Eligible
SS34L RVG | Taiwan Semiconductor Corporation | SS34LRVGCT-ND |  | D1 | Cut Tape (CT) | Active | 1 | 0.62000 | AU$0.62 | 8209 | 14 Weeks | DIODE SCHOTTKY 40V 3A SUB SMA | RoHS Compliant | Lead free | Not Available | Tariff Eligible
150080VS75000 | Wurth Electronics Inc. | 732-4986-1-ND |  | D4 | Cut Tape (CT) | Active | 1 | 0.26000 | AU$0.26 | 66003 | 13 Weeks | LED GREEN CLEAR 0805 SMD | RoHS Compliant | Lead free | REACH Unaffected | Tariff Eligible
150080BS75000 | Wurth Electronics Inc. | 732-4982-1-ND |  | D2 | Cut Tape (CT) | Active | 1 | 0.26000 | AU$0.26 | 28862 | 13 Weeks | LED BLUE CLEAR 0805 SMD | RoHS Compliant | Lead free | REACH Unaffected | Tariff Eligible
0ZCG0075FF2C | Bel Fuse Inc. | 507-1763-1-ND |  | F1 | Cut Tape (CT) | Active | 1 | 0.19000 | AU$0.19 | 349464 | 18 Weeks | PTC RESET FUSE 16V 750MA 1812 | RoHS Compliant | Lead free | REACH Unaffected
PH2-06-UA | Adam Tech | 2057-PH2-06-UA-ND |  | ISP1 | Bag | Active | 1 | 0.16000 | AU$0.16 | 2904 | 6 Weeks | PIN HEADER 6P 2.54MM PITCH PLUG | RoHS Compliant | Lead free | Not Available
S4B-PH-K-S(LF)(SN) | JST Sales America Inc. | 455-1721-ND |  | J2,J3 | Bulk | Active | 2 | 0.32000 | AU$0.64 | 328980 | 16 Weeks | CONN HEADER R/A 4POS 2MM | RoHS Compliant | Lead free | Not Available
S2B-PH-K-S(LF)(SN) | JST Sales America Inc. | 455-1719-ND |  | J1 | Bulk | Active | 1 | 0.25000 | AU$0.25 | 147801 | 20 Weeks | CONN HEADER R/A 2POS 2MM | RoHS Compliant | Lead free | Not Available
SI2312BDS-T1-E3 | Vishay Siliconix | SI2312BDS-T1-E3CT-ND |  | Q1 | Cut Tape (CT) | Active | 1 | 0.78000 | AU$0.78 | 124182 | 91 Weeks | MOSFET N-CH 20V 3.9A SOT23-3 | RoHS Compliant | Lead free | Not Available | Tariff Eligible
SQP10AJB-2R0 | Yageo | 2.0W-10-ND |  | R1 | Tray | Active | 1 | 1.19000 | AU$1.19 | 5587 | 14 Weeks | RES 2 OHM 10W 5% AXIAL | RoHS Compliant | Lead free | REACH Unaffected | Tariff Eligible
CRGCQ0805J4K7 | TE Connectivity Passive Product | A130138CT-ND |  | R2,R8,R10,R12 | Cut Tape (CT) | Active | 4 | 0.15000 | AU$0.60 | 86691 | 28 Weeks | CRGCQ 0805 4K7 5% | RoHS Compliant | Lead free | Not Available
RC0805FR-0720KL | Yageo | 311-20.0KCRCT-ND |  | R3 | Cut Tape (CT) | Active | 1 | 0.15000 | AU$0.15 | 4953656 | 16 Weeks | RES SMD 20K OHM 1% 1/8W 0805 | RoHS Compliant | Lead free | REACH Unaffected | Tariff Eligible
RMCF0805JT10K0 | Stackpole Electronics Inc | RMCF0805JT10K0CT-ND |  | R4 | Cut Tape (CT) | Active | 1 | 0.15000 | AU$0.15 | 553885 | 17 Weeks | RES 10K OHM 5% 1/8W 0805 | RoHS Compliant | Lead free | REACH Unaffected | Tariff Eligible
RC0805JR-07510KL | Yageo | 311-510KARCT-ND |  | R6 | Cut Tape (CT) | Active | 1 | 0.15000 | AU$0.15 | 65727 | 16 Weeks | RES SMD 510K OHM 5% 1/8W 0805 | RoHS Compliant | Lead free | REACH Unaffected | Tariff Eligible
RC0805JR-07680KL | Yageo | 311-680KARCT-ND |  | R7 | Cut Tape (CT) | Active | 1 | 0.15000 | AU$0.15 | 122071 | 16 Weeks | RES SMD 680K OHM 5% 1/8W 0805 | RoHS Compliant | Lead free | REACH Unaffected | Tariff Eligible
CRGCQ0805F47K | TE Connectivity Passive Product | A129769CT-ND |  | R9 | Cut Tape (CT) | Active | 1 | 0.15000 | AU$0.15 | 67042 | 28 Weeks | CRGCQ 0805 47K 1% | RoHS Compliant | Lead free | Not Available
B57891M0103K000 | EPCOS (TDK) | 495-75622-ND |  | TH1 | Bulk | Active | 1 | 1.44000 | AU$1.44 | 1269 | 16 Weeks | THERMISTOR NTC 10KOHM 3950K DISC | RoHS Compliant | Lead free | REACH Unaffected
REG710NA-3.3/3K | Texas Instruments | 296-39168-1-ND |  | U1 | Cut Tape (CT) | Active | 1 | 1.88000 | AU$1.88 | 30858 | 8 Weeks | IC REG CHARGE PUMP 3.3V SOT23 | RoHS Compliant | Lead free | REACH Unaffected | Tariff Eligible
ATTINY85V-10SU | Microchip Technology | ATTINY85V-10SU-ND |  | U3 | Tube | Active | 1 | 1.70000 | AU$1.70 | 965 | 4 Weeks | IC MCU 8BIT 8KB FLASH 8SOIC | RoHS Compliant | Lead free | REACH Unaffected
ADUM1250ARZ-RL7 | Analog Devices Inc. | ADUM1250ARZ-RL7CT-ND |  | U2 | Cut Tape (CT) | Active | 1 | 8.89000 | AU$8.89 | 12306 | 21 Weeks | DGTL ISO 2.5KV 2CH I2C 8SOIC | RoHS Compliant | Lead free | REACH Unaffected

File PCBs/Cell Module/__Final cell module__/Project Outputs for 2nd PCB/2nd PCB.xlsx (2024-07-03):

Line # | Name | Description | Designator | Quantity | Manufacturer 1 | Manufacturer Part Number 1 | Manufacturer Lifecycle 1 | Supplier 1 | Supplier Part Number 1 | Supplier Unit Price 1 | Supplier Subtotal 1
 | CC0805KRX7R9BB104 | 0.1ÂµF Â±10% 50V Ceramic Capacitor X7R 0805 _2012 Metric_ | C1_U1, C1_U2, C1_U3, C1_U4, C1_U5 | 5
 | CL21A106KAYNNNE | 10ÂµF Â±10% 25V Ceramic Capacitor X5R 0805 (2012 Metric) | C2_U1, C2_U2, C2_U3, C2_U4, C2_U5 | 5
 | AZ432ANTR-E1 | No Description Available | D1_U1, D1_U2, D1_U3, D1_U4, D1_U5 | 5
 | SM6T6V8A | TVS Diode (Uni-directional) | D2_U1, D2_U2, D2_U3, D2_U4, D2_U5 | 5
 | 598-2105-107F | LED | D3_U1, D3_U2, D3_U3, D3_U4, D3_U5 | 5
 | 19-217_GHC-YR1S2_3T | LED | D4_U1, D4_U2, D4_U3, D4_U4, D4_U5 | 5
 | MF-MSMF150-2 | Fuse | F1_U1, F1_U2, F1_U3, F1_U4, F1_U5 | 5
 | ATTINY1624-SSU | Integrated Circuit | IC1_U1, IC1_U2, IC1_U3, IC1_U4, IC1_U5 | 5
 | 7790 | Connector | J1, J2, J3 | 3
 | 212528-1001 | Connector | Power, Thermal | 2
 | AO3400A | No Description Available | Q1_U1, Q1_U2, Q1_U3, Q1_U4, Q1_U5 | 5
 | ERA6ARW104V |  | R1_U1, R1_U2, R1_U3, R1_U4, R1_U5 | 5
 | ERJU06J102V |  | R2_U1, R2_U2, R2_U3, R2_U4, R2_U5 | 5
 | ERJ6ENF1800V |  | R5_U1, R5_U2, R5_U3, R5_U4, R5_U5 | 5
 | RC2010JK-070RL | RES SMD 0 OHM JUMPER 3/4W 2010 | R6_U1, R6_U2, R6_U3, R6_U4, R6_U5, R8_U1, R8_U2, R8_U3, R8_U4, R8_U5, R10_U1, R10_U2, R10_U3, R10_U4, R10_U5, R22_U1, R22_U2, R22_U3, R22_U4, R22_U5, R24_U1, R24_U2, R24_U3, R24_U4, R24_U5, R25_U1, R25_U2, R25_U3, R25_U4, R25_U5, R26_U1, R26_U2, R26_U3, R26_U4, R26_U5, R27_U1, R27_U2, R27_U3, R27_U4, R27_U5, R28_U1, R28_U2, R28_U3, R28_U4, R28_U5 | 45
 | RT1206DRD07510RL | RES SMD 510 OHM 0.5% 1/8W 1206 | R14_U1, R14_U2, R14_U3, R14_U4, R14_U5 | 5
 | ERJP06D1002V |  | R15_U1, R15_U2, R15_U3, R15_U4, R15_U5, R20_U1, R20_U2, R20_U3, R20_U4, R20_U5, R21_U1, R21_U2, R21_U3, R21_U4, R21_U5 | 15
 | 0805W8F2201T5E | Resistor | R16_U1, R16_U2, R16_U3, R16_U4, R16_U5, R17_U1, R17_U2, R17_U3, R17_U4, R17_U5, R18_U1, R18_U2, R18_U3, R18_U4, R18_U5 | 15
 | NTCS0805E3104GMT | Thermistor | R19_U1, R19_U2, R19_U3, R19_U4, R19_U5 | 5
 | B2B-XH-A(LF)(SN) | Connector Header Through Hole 2 position 0.098 (2.50mm) | Rx, Tx | 2
 | EL3H7_B__TA_-G | Integrated Circuit | U1_U1, U1_U2, U1_U3, U1_U4, U1_U5 | 5
 | TS-103-T-A-1 | Connector Header position | UPDU1_U1, UPDU1_U2, UPDU1_U3, UPDU1_U4, UPDU1_U5 | 5

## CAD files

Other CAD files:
Solidworks/SW CONTROLLER/PW0024AakaMTC24.step.SLDASM
Solidworks/SW CONTROLLER/Terminal-1.step.SLDASM
Solidworks/SW CONTROLLER/6-69.step.SLDASM
Solidworks/SW CONTROLLER/Q2.step.SLDASM
Solidworks/SW CONTROLLER/C14.step.SLDASM
Solidworks/SW CONTROLLER/D4.step.SLDASM
Solidworks/SW CONTROLLER/R3.step.SLDASM
Solidworks/SW CONTROLLER/JP6.step.SLDASM
Solidworks/SW CONTROLLER/J7.step.SLDASM
Solidworks/SW CONTROLLER/4-73.step.SLDASM
Solidworks/SW CONTROLLER/J11.step.SLDASM
Solidworks/SW CONTROLLER/C3.step.SLDASM
Solidworks/SW CONTROLLER/C13.step.SLDASM
Solidworks/SW CONTROLLER/Conn_JST_B2B-XH-A_LF_SN_eec.step.SLDASM
Solidworks/SW CONTROLLER/R15.step.SLDASM
Solidworks/SW CONTROLLER/K4.step.SLDASM
Solidworks/SW CONTROLLER/R4.step.SLDASM
Solidworks/SW CONTROLLER/C17.step.SLDASM
PCBs/Cell Module/__Final cell module__/PCB with side mounts new.step
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

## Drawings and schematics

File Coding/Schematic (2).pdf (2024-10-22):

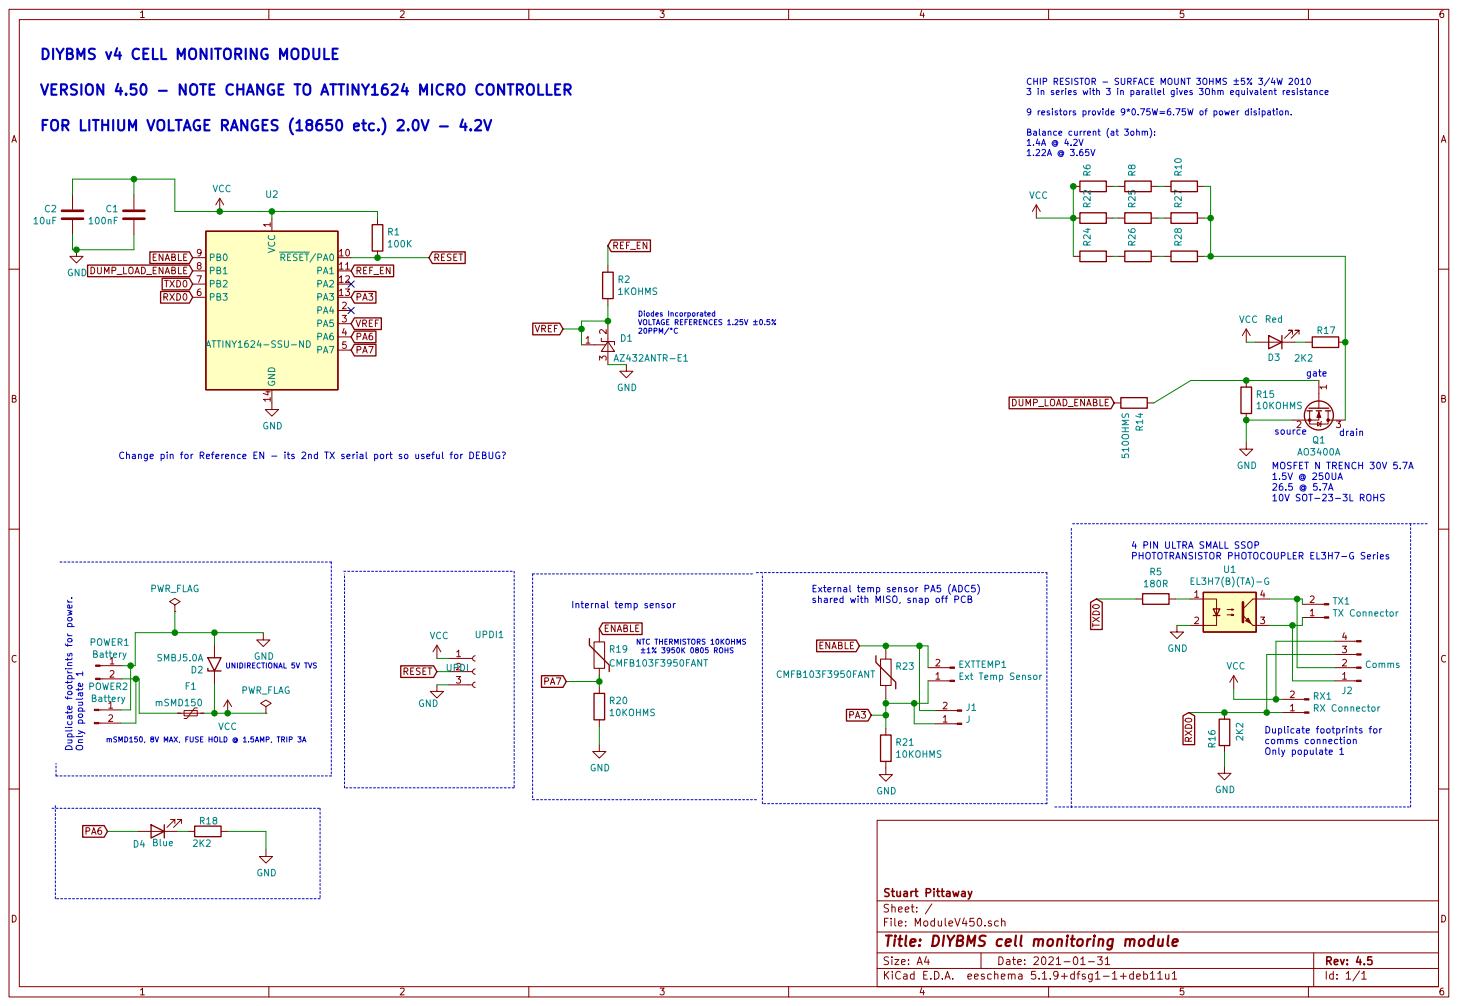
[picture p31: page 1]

DIYBMS v4 CELL MONITORING MODULE

source CHIP RESISTOR - SURFACE MOUNT 3OHMS ±5% 3/4W 2010
3 in series with 3 in parallel gives 3Ohm equivalent resistance

VERSION 4.50 - NOTE CHANGE TO ATTINY1624 MICRO CONTROLLER

9 resistors provide 9*0.75W=6.75W of power disipation. Balance current (at 3ohm): 1.4A @ 4.2V

FOR LITHIUM VOLTAGE RANGES (18650 etc.) 2.0V - 4.2V

1.22A @ 3.65V mSMD150, 8V MAX, FUSE HOLD @ 1.5AMP, TRIP 3A Duplicate footprints for power. Only populate 1

1 RESET/PA0 10 PA1 11 PA2 12 PA3 13 GND 14 PA4 2 PA5 3 PA6 4 PA7 5 PB3 6 PB2 7 PB1 8 PB0 9 U2 ATTINY1624-SSU-ND

PHOTOTRANSISTOR PHOTOCOUPLER EL3H7-G Series Change pin for Reference EN - its 2nd TX serial port so useful for DEBUG?

4 PIN ULTRA SMALL SSOP

shared with MISO, snap off PCB

Duplicate footprints for comms connection Only populate 1

File: ModuleV450.sch Sheet: / Stuart Pittaway

Id: 1/1 Title: DIYBMS cell monitoring module

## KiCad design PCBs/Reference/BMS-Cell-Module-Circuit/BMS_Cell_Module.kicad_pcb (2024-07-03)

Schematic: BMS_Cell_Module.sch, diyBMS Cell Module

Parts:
C1, C2: 2.2uF; C_0805_2012Metric_Pad1.33x1.40mm_HandSolder
C3, C4: 0.1uF; C_0805_2012Metric_Pad1.33x1.40mm_HandSolder
C5: 0.1uF polarized; C_0805_2012Metric_Pad1.33x1.40mm_HandSolder
C6: 0.22uF; C_0805_2012Metric_Pad1.33x1.40mm_HandSolder
D1: SS34 Schottky 40V/3A; DO-221AC
D2: LED BLUE; LED_0805_2012Metric_Pad1.15x1.40mm_HandSolder
D4: LED GREEN; LED_0805_2012Metric_Pad1.15x1.40mm_HandSolder
F1: FUSE; R_1812_4532Metric_Pad1.42x3.40mm_HandSolder
ISP1: Conn_02x03_Odd_Even; Pin_Header_Straight_2x03_Pitch2.54mm
J1: Conn_01x02_Female; JST_PH_S2B-PH-K_02x2.00mm_Angled
J2, J3: Conn_01x04_Female; JST_PH_S4B-PH-K_04x2.00mm_Angled
Q1: SI2312BDS-T1-E3; SOT-23
R1: 2R/10W; R_Axial_Power_L50.0mm_W9.0mm_P60.96mm
R2, R8, R10, R12: 4K7; R_0805_2012Metric_Pad1.33x1.40mm_HandSolder
R3: 20K; R_0805_2012Metric_Pad1.33x1.40mm_HandSolder
R4: 10K; R_0805_2012Metric_Pad1.33x1.40mm_HandSolder
R6: 510K; R_0805_2012Metric_Pad1.33x1.40mm_HandSolder
R7: 680K; R_0805_2012Metric_Pad1.33x1.40mm_HandSolder
R9: 47K; R_0805_2012Metric_Pad1.33x1.40mm_HandSolder
TH1: B57891M0103K000; R_Axial_DIN0204_L3.6mm_D1.6mm_P2.54mm_Vertical
TP1: VDIV; TestPoint_Pad_D1.5mm
TP2: TPGND; TestPoint_Pad_D1.5mm
U1: REG710NA-3.3; SOT-23-6_Handsoldering
U2: ADUM1250ARZ; SOIC-8_3.9x4.9mm_P1.27mm
U3: ATTINY85V-10SU 8S2 EIAJ SOIC; SOIJ-8_5.3x5.3mm_P1.27mm

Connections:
3V3: C2.1, C4.1, C5.1, ISP1.2, R3.1, R8.2, R10.2, TH1.1, U1.1, U2.1, U3.8 (VCC)
/MISO: D4.2, ISP1.1, U3.6 (PB1)
/MOSI: ISP1.4, R8.1, U2.2, U3.5 (AREF/PB0)
/PB4BYPASS: Q1.1, R9.1, U3.3 (XTAL2/PB4)
/RST: ISP1.5, R3.2, R4.1, TH1.2, U3.1 (~RESET~/PB5)
/SCK: ISP1.3, R10.1, U2.3, U3.7 (PB2)
BATT+RAW: D1.2, J1.2, R6.1
GND: C1.2, C2.2, C3.2, C4.2, C5.2, ISP1.6, J1.1, Q1.2, R4.2, R7.2, R9.2, R12.2, TP2.1, U1.2, U2.4, U3.4 (GND)
unnamed: C1.1, D2.2, F1.1, R1.2, U1.3, U1.5
unnamed: C3.1, R6.2, R7.1, TP1.1, U3.2 (XTAL1/PB3)
unnamed: C6.1, U1.6
unnamed: C6.2, U1.4
unnamed: D1.1, F1.2
unnamed: D2.1, R2.2
unnamed: D4.1, R12.1
unnamed: J2.1, J3.1, U2.8
unnamed: J2.2, J3.2, U2.7
unnamed: J2.3, J3.3, U2.6
unnamed: J2.4, J3.4, U2.5
unnamed: Q1.3, R1.1, R2.1

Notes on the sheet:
Battery voltage divider 1.8→4.5V maps to ADC3=1.029V→2.571V
Li-Ion battery input 1.8→4.5V
C1/C2/C6 ceramic, X7R or X5R
2-channel bidirectional digital isolator for external I2C bus
side 1 strict I2C
side 2 relaxed I2C
Power resistor 10→50W
gate
source
drain
N-channel MOSFET

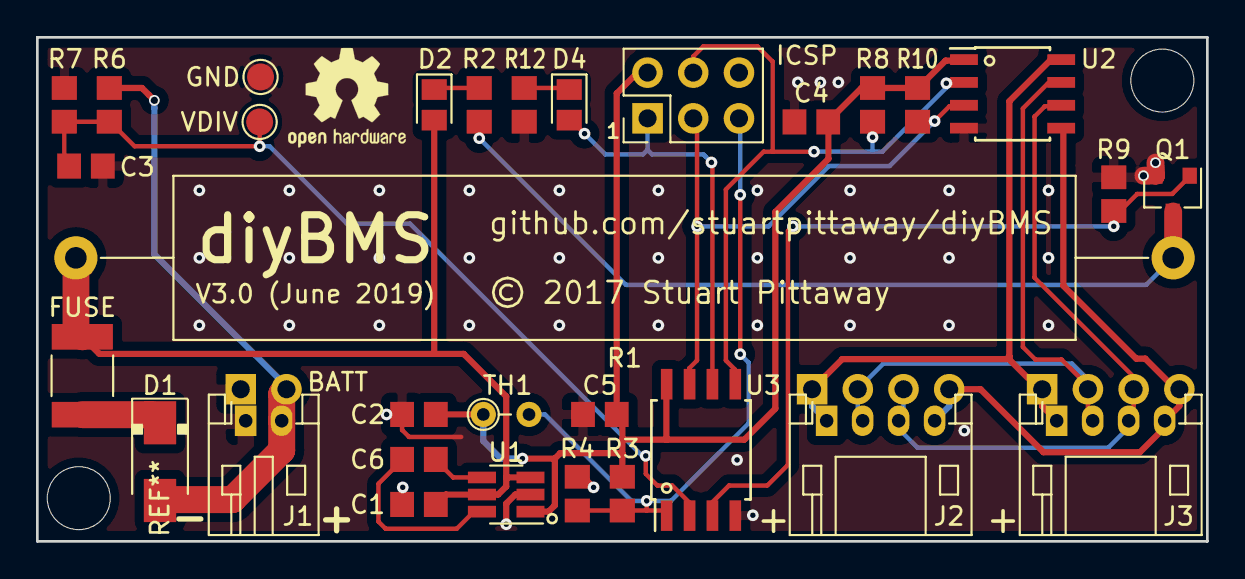
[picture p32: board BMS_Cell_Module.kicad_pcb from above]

Board: 2 copper layers, 65.0 x 28.0 mm, 31 parts (0 on the bottom side), 20 nets.

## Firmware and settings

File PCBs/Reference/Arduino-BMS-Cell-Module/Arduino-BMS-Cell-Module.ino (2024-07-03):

/*
   ____  ____  _  _  ____  __  __  ___
  (  _ \(_  _)( \/ )(  _ \(  \/  )/ __)
   )(_) )_)(_  \  /  ) _ < )    ( \__ \
  (____/(____) (__) (____/(_/\/\_)(___/

  (c) 2017/2018 Stuart Pittaway

  This is the code for the cell module (one is needed for each series cell in a modular battery array (pack))

  This code runs on ATTINY85 processors and compiles with Arduino 1.8.5 environment

  You will need a seperate programmer to program the ATTINY chips - another Arduino can be used

  Settings ATTINY85, 8MHZ INTERNAL CLOCK, LTO enabled, BOD disabled, Timer1=CPU


  Use this board manager for ATTINY85
  http://drazzy.com/package_drazzy.com_index.json
  not this one https://raw.githubusercontent.com/damellis/attiny/ide-1.6.x-boards-manager/package_damellis_attiny_index.json

  ATTINY85/V-10PU data sheet
  http://www.atmel.com/images/atmel-2586-avr-8-bit-microcontroller-attiny25-attiny45-attiny85_datasheet.pdf

  To manually configure ATTINY fuses use the command....
  .\bin\avrdude -p attiny85 -C etc\avrdude.conf -c avrisp -P COM5 -b 19200 -B2 -e -Uefuse:w:0xff:m -Uhfuse:w:0xdf:m -Ulfuse:w:0xe2:m
  If you burn incorrect fuses to ATTINY85 you may need to connect a crystal over the pins to make it work again!
*/


//Show error is not targetting ATTINY85
#if !(defined(__AVR_ATtiny85__))
#error Written for ATTINY85/V chip
#endif

#if !(F_CPU == 8000000)
#error Processor speed should be 8Mhz internal dont forget to burn the bootloader/fuses!
#endif

#include <USIWire.h>
#include <EEPROM.h>
#include <avr/sleep.h>
#include <avr/wdt.h>

// __DATE__

//LED light patterns
#define GREEN_LED_PATTERN_STANDARD 0
#define GREEN_LED_PATTERN_BYPASS B01101100
#define GREEN_LED_PANIC B01010101
#define GREEN_LED_PATTERN_UNCONFIGURED B11101111

//Where in EEPROM do we store the configuration
#define EEPROM_CHECKSUM_ADDRESS 0
#define EEPROM_CONFIG_ADDRESS 20

#define MIN_BYPASS_VOLTAGE 3000U
#define MAX_BYPASS_VOLTAGE 4200U

//Number of TIMER1 cycles between voltage reading checks (240 = approx 30 seconds)
#define BYPASS_COUNTER_MAX 240

//Default i2c SLAVE address (used for auto provision of address)
#define DEFAULT_SLAVE_ADDR 21

//Configured cell modules use i2c addresses 24 to 48 (24S)
#define DEFAULT_SLAVE_ADDR_START_RANGE 24
#define DEFAULT_SLAVE_ADDR_END_RANGE DEFAULT_SLAVE_ADDR_START_RANGE + 24

//Number of times we sample and average the ADC for voltage
#define OVERSAMPLE_LOOP 16

//If we receive a cmdByte with BIT 6 set its a command byte so there is another byte waiting for us to process
#define COMMAND_BIT 6

#define COMMAND_green_led_pattern   1
//unused #define COMMAND_led_off   2
#define COMMAND_factory_default 3
#define COMMAND_set_slave_address 4
#define COMMAND_green_led_default 5
#define COMMAND_set_voltage_calibration 6
#define COMMAND_set_temperature_calibration 7
#define COMMAND_set_bypass_voltage 8
#define COMMAND_set_load_resistance 9


#define read_voltage 10
#define read_temperature 11
#define read_voltage_calibration 12
#define read_temperature_calibration 13
#define read_raw_voltage 14
#define read_error_counter 15
#define read_bypass_enabled_state 16
#define read_bypass_voltage_measurement 17
#define read_load_resistance 18

volatile bool skipNextADC = false;
volatile uint8_t green_pattern = GREEN_LED_PATTERN_STANDARD;
volatile uint16_t analogVal[OVERSAMPLE_LOOP];
volatile uint16_t temperature_probe = 0;
volatile uint8_t analogValIndex;
volatile uint8_t buffer_ready = 0;
volatile uint8_t reading_count = 0;
volatile uint8_t cmdByte = 0;

volatile uint8_t last_i2c_request = 255;
volatile uint16_t VCCMillivolts = 0;
volatile uint16_t ByPassVCCMillivolts = 0;
volatile uint16_t last_raw_adc = 0;
volatile uint16_t targetByPassVoltage = 0;
volatile uint8_t ByPassCounter = 0;
volatile boolean ByPassEnabled = false;
volatile boolean flash_green = false;

uint16_t error_counter = 0;

bool flashLed;

//Number of voltage readings to take before we take a temperature reading
#define TEMP_READING_LOOP_FREQ 16

//Default values
struct cell_module_config {
  // 7 bit slave I2C address
  uint8_t SLAVE_ADDR = DEFAULT_SLAVE_ADDR;
  // Calibration factor for voltage readings
  float VCCCalibration = 4.430;
  // Calibration factor for temp readings
  float TemperatureCalibration = 1.080;
  // Resistance of bypass load
  float LoadResistance = 10.0;
};

static cell_module_config myConfig;

void setup() {
  //Must be first line of setup()
  MCUSR &= ~(1 << WDRF); // reset status flag
  wdt_disable();

  //Pins PB0 (SDA) and PB2 (SCLOCK) are for the i2c comms with master
  //PINS https://github.com/SpenceKonde/ATTinyCore/blob/master/avr/extras/ATtiny_x5.md

  //pinMode(A3, INPUT);  //A3 pin 3 (PB3)
  //pinMode(A0, INPUT);  //reset pin A0 pin 5 (PB5)

  /*
    DDRB &= ~(1 << DDB3);
    PORTB &= ~(1 << PB3);

    DDRB &= ~(1 << DDB5);
    PORTB &= ~(1 << PB5);
  */

  pinMode(PB4, OUTPUT); //PB4 = PIN 3
  digitalWrite(PB4, LOW);

  ledGreen();
  delay(500);
  ledOff();

  //Load our EEPROM configuration
  if (!LoadConfigFromEEPROM()) {
    //Do something here for bad configuration??
  }

  cli();//stop interrupts

  analogValIndex = 0;

  initTimer1();
  initADC();

  // WDTCSR configuration:     WDIE = 1: Interrupt Enable     WDE = 1 :Reset Enable
  // Enter Watchdog Configuration mode:
  WDTCR |= (1 << WDCE) | (1 << WDE);

  // Set Watchdog settings - 4000ms timeout
  WDTCR = (1 << WDIE) | (1 << WDE) | (1 << WDP3) | (0 << WDP2) | (0 << WDP1) | (0 << WDP0);

  // Enable Global Interrupts
  sei();

  LEDReset();
  wait_for_buffer_ready();
  LEDReset();

  init_i2c();
}

boolean inPanicMode = false;

void panic() {
  green_pattern = GREEN_LED_PANIC;
  inPanicMode = true;
}

uint8_t previousLedState = 0;
void loop() {
  wdt_reset();

  if (last_i2c_request > 0) {
    //Count down loop for requests to see if i2c bus hangs or controller stops talking
    last_i2c_request--;
  }

  //If we are on the default SLAVE address then use different LED pattern to indicate this
  if (myConfig.SLAVE_ADDR == DEFAULT_SLAVE_ADDR) {
    green_pattern = GREEN_LED_PATTERN_UNCONFIGURED;
  } else {
    //We have had at least one i2c request and not currently in PANIC mode
    if (last_i2c_request == 0 && inPanicMode == false) {

      previousLedState = green_pattern ;

      //Panic after a few seconds of not receiving i2c requests...
      panic();

      //Try resetting the i2c bus
      Wire.end();
      init_i2c();

      error_counter++;
    }

    if (last_i2c_request > 0 && inPanicMode == true) {
      //Just come back from a PANIC situation
      LEDReset();
      green_pattern = previousLedState;
      inPanicMode = false;
    }

  }

  //Dont make this very large or watchdog will reset
  delay(250);
}

uint32_t calculateCRC32(const uint8_t *data, size_t length)
{
  uint32_t crc = 0xffffffff;
  while (length--) {
    uint8_t c = *data++;
    for (uint32_t i = 0x80; i > 0; i >>= 1) {
      bool bit = crc & 0x80000000;
      if (c & i) {
        bit = !bit;
      }
      crc <<= 1;
      if (bit) {
        crc ^= 0x04c11db7;
      }
    }
  }
  return crc;
}

void WriteConfigToEEPROM() {
  EEPROM.put(EEPROM_CONFIG_ADDRESS, myConfig);
  EEPROM.put(EEPROM_CHECKSUM_ADDRESS, calculateCRC32((uint8_t*)&myConfig, sizeof(cell_module_config)));
}

bool LoadConfigFromEEPROM() {
  cell_module_config restoredConfig;
  uint32_t existingChecksum;

  EEPROM.get(EEPROM_CONFIG_ADDRESS, restoredConfig);
  EEPROM.get(EEPROM_CHECKSUM_ADDRESS, existingChecksum);

  // Calculate the checksum of an entire buffer at once.
  uint32_t checksum = calculateCRC32((uint8_t*)&restoredConfig, sizeof(cell_module_config));

  if (checksum == existingChecksum) {
    //Clone the config into our global variable and return all OK
    memcpy(&myConfig, &restoredConfig, sizeof(cell_module_config));
    return true;
  }

  //Config is not configured or gone bad, return FALSE
  return false;
}

void init_i2c() {
  Wire.begin(myConfig.SLAVE_ADDR);
  Wire.onRequest(requestEvent);
  Wire.onReceive(receiveEvent);
}

void LEDReset() {
  green_pattern = GREEN_LED_PATTERN_STANDARD;
}

void factory_default() {
  EEPROM.put(EEPROM_CHECKSUM_ADDRESS, 0);
}

void Reboot() {
  TCCR1 = 0;
  TIMSK |= (1 << OCIE1A); //Disable timer1

  //Now power down loop until the watchdog timer kicks a reset
  ledGreen();

  /*
    set_sleep_mode(SLEEP_MODE_PWR_DOWN);
    adc_disable();
    sleep_enable();
    sleep_cpu();
  */
  //Infinity
  while (1) {}
}

void wait_for_buffer_ready() {
  //Just delay here so the buffers are all ready before we service i2c
  while (!buffer_ready) {
    delay(100);
    wdt_reset();
  }
}


void sendUnsignedInt(uint16_t number) {
  Wire.write((byte)((number >> 8) & 0xFF));
  Wire.write((byte)(number & 0xFF));
}

void sendByte(uint8_t number) {
  Wire.write(number);
}


union {
  float val;
  uint8_t b[4];
} float_to_bytes;

void sendFloat(float number) {
  float_to_bytes.val = number;

  Wire.write(float_to_bytes.b[0]);
  Wire.write(float_to_bytes.b[1]);
  Wire.write(float_to_bytes.b[2]);
  Wire.write(float_to_bytes.b[3]);
}

float readFloat() {
  float_to_bytes.b[0] = Wire.read();
  float_to_bytes.b[1] = Wire.read();
  float_to_bytes.b[2] = Wire.read();
  float_to_bytes.b[3] = Wire.read();

  return float_to_bytes.val;
}

void bypass_off() {
  targetByPassVoltage = 0;
  ByPassCounter = 0;
  ByPassEnabled = false;
  green_pattern = GREEN_LED_PATTERN_STANDARD;
}

union {
  uint16_t val;
  uint8_t b[2];
} uint16_t_to_bytes;

uint16_t readUINT16() {
  uint16_t_to_bytes.b[0] = Wire.read();
  uint16_t_to_bytes.b[1] = Wire.read();
  return uint16_t_to_bytes.val;
}

// function that executes whenever data is received from master
void receiveEvent(int howMany) {
  if (howMany <= 0) return;

  //If cmdByte is not zero then something went wrong in the i2c comms,
  //master failed to request any data after command
  if (cmdByte != 0) error_counter++;

  flashLed = true;

  cmdByte = Wire.read();
  howMany--;

  //Is it a command byte (there are other bytes to process) or not?
  if (bitRead(cmdByte, COMMAND_BIT)) {

    bitClear(cmdByte, COMMAND_BIT);

    switch (cmdByte) {
      case COMMAND_green_led_pattern:
        if (howMany == 1) {
          green_pattern = Wire.read();
        }
        break;

      case COMMAND_green_led_default:
        green_pattern = GREEN_LED_PATTERN_STANDARD;
        break;

      case COMMAND_factory_default:
        factory_default();
        Reboot();
        break;

      case COMMAND_set_voltage_calibration:
        if (howMany == sizeof(float)) {
          float newValue = readFloat();
          //Only accept if its different
          if (newValue != myConfig.VCCCalibration) {
            myConfig.VCCCalibration = newValue;
            WriteConfigToEEPROM();
          }
        }
        break;

      case COMMAND_set_temperature_calibration:
        if (howMany == sizeof(float)) {
          float newValue = readFloat();
          //Only accept if its different
          if (newValue != myConfig.TemperatureCalibration) {
            myConfig.TemperatureCalibration = newValue;
            WriteConfigToEEPROM();
          }
        }
        break;

      case COMMAND_set_load_resistance:
        if (howMany == sizeof(float)) {
          float newValue = readFloat();
          //Only accept if its different
          if (newValue != myConfig.LoadResistance) {
            myConfig.LoadResistance = newValue;
            WriteConfigToEEPROM();
          }
        }
        break;

      case COMMAND_set_bypass_voltage:
        if (howMany == sizeof(uint16_t)) {
          uint16_t newValue = readUINT16();
          //Only accept if its a realistic value and the value is LESS than the last voltage reading
          if (newValue >= MIN_BYPASS_VOLTAGE && newValue <= MAX_BYPASS_VOLTAGE && newValue < VCCMillivolts) {
            //TODO: Are we sure we really need all these variables??
            targetByPassVoltage = newValue;
            ByPassVCCMillivolts = VCCMillivolts;
            ByPassCounter = BYPASS_COUNTER_MAX;
            green_pattern = GREEN_LED_PATTERN_BYPASS;
            ByPassEnabled = true;
          } else {
            //Disable
            bypass_off();
          }
        }
        break;


      case COMMAND_set_slave_address:
        //Set i2c slave address and write to EEPROM, then reboot
        if (howMany == 1 ) {
          uint8_t newAddress = Wire.read();
          //Only accept if its a different address
          if (newAddress != myConfig.SLAVE_ADDR && newAddress >= DEFAULT_SLAVE_ADDR_START_RANGE && newAddress <= DEFAULT_SLAVE_ADDR_END_RANGE) {
            myConfig.SLAVE_ADDR = newAddress;
            WriteConfigToEEPROM();
            Reboot();
          }
        }
        break;

    }

    cmdByte = 0;
  } else {
    //Its a READ request

    switch (cmdByte) {
      case read_voltage:
        VCCMillivolts = Update_VCCMillivolts();
        flash_green = true;
        break;
    }
  }

  // clear rx buffer
  while (Wire.available()) Wire.read();
}


float Update_VCCMillivolts() {
  //Oversampling and take average of ADC samples use an unsigned integer or the bit shifting goes wonky
  uint32_t extraBits = 0;
  for (int k = 0; k < OVERSAMPLE_LOOP; k++) {
    extraBits = extraBits + analogVal[k];
  }
  //Shift the bits to match OVERSAMPLE_LOOP size (buffer size of 8=3 shifts, 16=4 shifts)
  uint16_t raw = (extraBits >> 4);

  //TODO: Get rid of the need for float variables....
  return (int)((float)raw * myConfig.VCCCalibration);
}

// function that executes whenever data is requested by master (this answers requestFrom command)
void requestEvent() {
  switch (cmdByte) {
    case read_voltage:
      //If we are in bypass then only return the voltage
      //thats taken outside of the resistor load being switched on
      if (ByPassEnabled) {
        sendUnsignedInt(ByPassVCCMillivolts);
      } else {
        sendUnsignedInt(VCCMillivolts);
      }

      break;

    case read_raw_voltage:
      sendUnsignedInt(last_raw_adc);
      break;

    case read_error_counter:
      sendUnsignedInt(error_counter);
      break;

    case read_bypass_voltage_measurement:
      sendUnsignedInt(ByPassVCCMillivolts);
      break;

    case read_bypass_enabled_state:
      sendByte(ByPassEnabled);
      break;

    case read_temperature:
      sendUnsignedInt((uint16_t)((float)temperature_probe * myConfig.TemperatureCalibration));
      break;

    case read_voltage_calibration:
      sendFloat(myConfig.VCCCalibration);
      break;

    case read_temperature_calibration:
      sendFloat(myConfig.TemperatureCalibration);
      break;

    case read_load_resistance:
      sendFloat(myConfig.LoadResistance);
      break;

    default:
      //Dont do anything - timeout
      break;
  }

  //Clear cmdByte
  cmdByte = 0;

  //Reset when we last processed a request, if this times out master has stopped communicating with module
  last_i2c_request = 150;
}

inline void ledGreen() {
  DDRB |= (1 << DDB1);
  PORTB |=  (1 << PB1);
}

/*
  inline void ledRed() {
  DDRB |= (1 << DDB1);
  PORTB &= ~(1 << PB1);
  }
*/
inline void ledOff() {
  //Low
  DDRB |= (1 << DDB1);
  PORTB &= ~(1 << PB1);
  /*
    //PB1 as input
    DDRB &= ~(1 << DDB1);
    //PB1 pull up OFF
    PORTB &= ~(1 << PB1);
  */
}

ISR(TIMER1_COMPA_vect)
{
  //Flash LED in sync with bit pattern


  if (green_pattern == 0) {
    if (flash_green)  {
      ledGreen();
    }
    flash_green = false;
  } else {
    ///Rotate pattern
    green_pattern = (byte)(green_pattern << 1) | (green_pattern >> 7);

    if (green_pattern & 0x01) {
      ledGreen();
    } else {
      ledOff();
    }
  }

  if (ByPassEnabled) {

    //TODO: We need to add in code here to check we don't overheat

    //This must go above the following "if (ByPassCounter > 0)" statement...
    if (ByPassCounter == 0 && analogValIndex == 0) {
      //We are in bypass and just finished an in-cycle voltage measurement
      ByPassVCCMillivolts = Update_VCCMillivolts();

      if (targetByPassVoltage >= ByPassVCCMillivolts) {
        //We reached the goal
        bypass_off();
      } else {
        //Try again
        ByPassCounter = BYPASS_COUNTER_MAX;
      }
    }

    if (ByPassCounter > 0)
    {
      //We are in ACTIVE BYPASS mode - the RESISTOR will be ACTIVE + BURNING ENERGY
      ByPassCounter--;
      digitalWrite(PB4, HIGH);

      if (ByPassCounter == 0)
      {
        //We have just finished this timed ACTIVE BYPASS mode, disable resistor
        //and measure resting voltage now before possible re-enable.
        digitalWrite(PB4, LOW);

        //Reset voltage ADC buffer
        analogValIndex = 0;
      }
    }

  } else {
    //Safety check we ensure bypass is always off if not enabled
    digitalWrite(PB4, LOW);
  }

  if (green_pattern == 0) {
    ledOff();
  }


  //trigger ADC reading
  ADCSRA |= (1 << ADSC);
}

ISR(ADC_vect) {
  // Interrupt service routine for the ADC completion
  //uint8_t adcl = ADCL;
  //uint16_t value = ADCH << 8 | adcl;

  uint16_t value = ADCW;

  //If we skip this ADC reading, quit ISR here
  if (skipNextADC) {
    skipNextADC = false;
    return;
  }

  if (reading_count == TEMP_READING_LOOP_FREQ ) {
    //Use A0 (RESET PIN) to act as an analogue input
    //note that we cannot take the pin below 1.4V or the CPU resets
    reading_count = 0;

    //We reduce the value by 512 as we have a DC offset we need to remove
    temperature_probe = value;

    //use ADC3 for input for next reading (voltage)
    ADMUX = B10010011;

    //Set skipNextADC to delay the next TIMER1 call to ADC reading to allow the ADC to settle after changing MUX
    skipNextADC = true;

  } else {

    //Populate the rolling buffer with values from the ADC
    last_raw_adc = value;
    analogVal[analogValIndex] = value;

    analogValIndex++;

    if (analogValIndex == OVERSAMPLE_LOOP) {
      analogValIndex = 0;
      buffer_ready = 1;
    }

    reading_count++;

    if (reading_count == TEMP_READING_LOOP_FREQ) {
      //use ADC0 for temp probe input on next ADC loop

      ADMUX = B10010000;

      //Set skipNextADC to delay the next TIMER1 call to ADC reading to allow the ADC to settle after changing MUX
      skipNextADC = true;
    }
  }

}

void initADC()
{
  /* this function initialises the ADC

        ADC Prescaler Notes:
    --------------------

     ADC Prescaler needs to be set so that the ADC input frequency is between 50 - 200kHz.

           For more information, see table 17.5 "ADC Prescaler Selections" in
           chapter 17.13.2 "ADCSRA – ADC Control and Status Register A"
          (pages 140 and 141 on the complete ATtiny25/45/85 datasheet, Rev. 2586M–AVR–07/10)

           Valid prescaler values for various clock speeds

       Clock   Available prescaler values
           ---------------------------------------
             1 MHz   8 (125kHz), 16 (62.5kHz)
             4 MHz   32 (125kHz), 64 (62.5kHz)
             8 MHz   64 (125kHz), 128 (62.5kHz)
            16 MHz   128 (125kHz)


    ADPS2 ADPS1 ADPS0 Division Factor
    000 2
    001 2
    010 4
    011 8
    100 16
    101 32
    110 64
    111 128

  */

  //NOTE The device requries a supply voltage of 3V+ in order to generate 2.56V reference voltage.
  // http://openenergymonitor.blogspot.co.uk/2012/08/low-level-adc-control-admux.html

  //REFS1 REFS0 ADLAR REFS2 MUX3 MUX2 MUX1 MUX0
  //Internal 2.56V Voltage Reference without external bypass capacitor, disconnected from PB0 (AREF)
  //ADLAR =0 and PB3 (B0011) for INPUT (A3)
  //We have to set the registers directly because the ATTINYCORE appears broken for internal 2v56 register without bypass capacitor
  ADMUX = B10010011;

  /*
    ADMUX = (INTERNAL2V56_NO_CAP << 4) |
          (0 << ADLAR)  |     // dont left shift ADLAR
          (0 << MUX3)  |     // use ADC3 for input (PB4), MUX bit 3
          (0 << MUX2)  |     // use ADC3 for input (PB4), MUX bit 2
          (1 << MUX1)  |     // use ADC3 for input (PB4), MUX bit 1
          (1 << MUX0);       // use ADC3 for input (PB4), MUX bit 0
  */

  /*
    #if (F_CPU == 1000000)
    //Assume 1MHZ clock so prescaler to 8 (B011)
    ADCSRA =
      (1 << ADEN)  |     // Enable ADC
      (0 << ADPS2) |     // set prescaler bit 2
      (1 << ADPS1) |     // set prescaler bit 1
      (1 << ADPS0);      // set prescaler bit 0
    #endif
  */
  //#if (F_CPU == 8000000)
  //8MHZ clock so set prescaler to 64 (B110)
  ADCSRA =
    (1 << ADEN)  |     // Enable ADC
    (1 << ADPS2) |     // set prescaler bit 2
    (1 << ADPS1) |     // set prescaler bit 1
    (0 << ADPS0) |       // set prescaler bit 0
    (1 << ADIE);     //enable the ADC interrupt.
  //#endif
}

static inline void initTimer1(void)
{
  TCCR1 |= (1 << CTC1);  // clear timer on compare match
  TCCR1 |= (1 << CS13) | (1 << CS12) | (1 << CS11) | (1 << CS10); //clock prescaler 16384
  OCR1C = 64;  //About eighth of a second trigger Timer1  (there are 488 counts per second @ 8mhz)
  TIMSK |= (1 << OCIE1A); // enable compare match interrupt
}

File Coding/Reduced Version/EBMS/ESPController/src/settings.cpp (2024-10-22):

#define USE_ESP_IDF_LOG 1
static constexpr const char *const TAG = "Ebms-set";

#include "settings.h"

/*
THESE STRINGS ARE USED AS KEYS IN THE JSON SETTINGS BACKUP FILES
DEFINED HERE (ONCE) TO ENSURE TYPOS ARE NOT MADE
*/
static const char totalNumberOfBanks_JSONKEY[] = "totalNumberOfBanks";
static const char totalNumberOfSeriesModules_JSONKEY[] = "totalNumberOfSeriesModules";
static const char baudRate_JSONKEY[] = "baudRate";
static const char interpacketgap_JSONKEY[] = "interpacketgap";
static const char graph_voltagehigh_JSONKEY[] = "graph_voltagehigh";
static const char graph_voltagelow_JSONKEY[] = "graph_voltagelow";
static const char BypassOverTempShutdown_JSONKEY[] = "BypassOverTempShutdown";
static const char BypassThresholdmV_JSONKEY[] = "BypassThresholdmV";
static const char timeZone_JSONKEY[] = "timeZone";
static const char minutesTimeZone_JSONKEY[] = "minutesTimeZone";
static const char daylight_JSONKEY[] = "daylight";
static const char ntpServer_JSONKEY[] = "ntpServer";
static const char loggingEnabled_JSONKEY[] = "loggingEnabled";
static const char loggingFrequencySeconds_JSONKEY[] = "loggingFrequencySeconds";
static const char currentMonitoringEnabled_JSONKEY[] = "currentMonitoringEnabled";
static const char currentMonitoringModBusAddress_JSONKEY[] = "currentMonitoringModBusAddress";
static const char rs485baudrate_JSONKEY[] = "rs485baudrate";
static const char rs485databits_JSONKEY[] = "rs485databits";
static const char rs485parity_JSONKEY[] = "rs485parity";
static const char rs485stopbits_JSONKEY[] = "rs485stopbits";
static const char language_JSONKEY[] = "language";
static const char mqtt_enabled_JSONKEY[] = "enabled";
static const char mqtt_basic_cell_reporting_JSONKEY[] = "basiccellrpt";
static const char mqtt_uri_JSONKEY[] = "uri";
static const char mqtt_topic_JSONKEY[] = "topic";
static const char mqtt_username_JSONKEY[] = "username";
static const char mqtt_password_JSONKEY[] = "password";
static const char influxdb_enabled_JSONKEY[] = "enabled";
static const char influxdb_apitoken_JSONKEY[] = "apitoken";
static const char influxdb_databasebucket_JSONKEY[] = "bucket";
static const char influxdb_orgid_JSONKEY[] = "org";
static const char influxdb_serverurl_JSONKEY[] = "url";
static const char influxdb_loggingFreqSeconds_JSONKEY[] = "logfreq";
static const char canbusprotocol_JSONKEY[] = "canbusprotocol";
static const char canbusinverter_JSONKEY[] = "canbusinverter";
static const char canbusbaud_JSONKEY[] = "canbusbaud";
static const char canbus_equipment_addr_JSONKEY[] = "canbusequip";
static const char nominalbatcap_JSONKEY[] = "nominalbatcap";
static const char chargevolt_JSONKEY[] = "chargevolt";
static const char chargecurrent_JSONKEY[] = "chargecurrent";
static const char dischargecurrent_JSONKEY[] = "dischargecurrent";
static const char dischargevolt_JSONKEY[] = "dischargevolt";
static const char chargetemplow_JSONKEY[] = "chargetemplow";
static const char chargetemphigh_JSONKEY[] = "chargetemphigh";
static const char dischargetemplow_JSONKEY[] = "dischargetemplow";
static const char dischargetemphigh_JSONKEY[] = "dischargetemphigh";
static const char stopchargebalance_JSONKEY[] = "stopchargebalance";
static const char socoverride_JSONKEY[] = "socoverride";
static const char socforcelow_JSONKEY[] = "socforcelow";
static const char dynamiccharge_JSONKEY[] = "dynamiccharge";
static const char preventdischarge_JSONKEY[] = "preventdischarge";
static const char preventcharging_JSONKEY[] = "preventcharging";
static const char cellminmv_JSONKEY[] = "cellminmv";
static const char cellmaxmv_JSONKEY[] = "cellmaxmv";
static const char kneemv_JSONKEY[] = "kneemv";
static const char cellmaxspikemv_JSONKEY[] = "cellmaxspikemv";
static const char sensitivity_JSONKEY[] = "sensitivity";
static const char current_value1_JSONKEY[] = "cur_val1";
static const char current_value2_JSONKEY[] = "cur_val2";

static const char currentMonitoringDevice_JSONKEY[] = "currentMonitoringDevice";
static const char currentMonitoring_shuntmv_JSONKEY[] = "currentMonitoringShuntmv";
static const char currentMonitoring_shuntmaxcur_JSONKEY[] = "currentMonitoringShuntMaxCur";
static const char currentMonitoring_batterycapacity_JSONKEY[] = "currentMonitoringBatteryCap";
static const char currentMonitoring_fullchargevolt_JSONKEY[] = "currentMonitoringFullChargeVolt";
static const char currentMonitoring_tailcurrent_JSONKEY[] = "currentMonitoringTailCurrent";
static const char currentMonitoring_chargeefficiency_JSONKEY[] = "currentMonitoringChargeEfficiency";
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

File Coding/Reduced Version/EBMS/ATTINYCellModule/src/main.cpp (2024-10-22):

//Select Environment: env:V450_5k(ATTINYCellModule)
//Also Try in Desktop

#define RX_BUFFER_SIZE 64

#include "IOlib.h"

#include "Ebms_tinyAVR2.h"

#if !defined(EBMSBAUD)
#error Expected EBMSBAUD define
#endif

#if !defined(SAMPLEAVERAGING)
#error Expected SAMPLEAVERAGING define
#endif

// Our project code includes
#include "defines.h"
#include "settings.h"
#include <FastPID.h>
#include <SerialEncoder.h>
#include "packet_processor.h"

uint8_t SerialPacketReceiveBuffer[8 + sizeof(PacketStruct)];

SerialEncoder myPacketSerial;

// Default values which get overwritten by EEPROM on power up
CellModuleConfig myConfig;

PacketProcessor PP(&myConfig);

volatile bool wdt_triggered = false;

// Interrupt counter
volatile uint8_t InterruptCounter = 0;
volatile uint16_t PulsePeriod = 0;
volatile uint16_t OnPulseCount = 0;

void DefaultConfig()
{
myConfig.Calibration = 1.0;


#if defined(EBMSMODULEVERSION) && (EBMSMODULEVERSION == 420 && !defined(SWAPR19R20))
  // Keep temperature low for modules with R19 and R20 not swapped
  myConfig.BypassTemperatureSetPoint = 45;
#else
  // Stop running bypass if temperature over 65 degrees C
  myConfig.BypassTemperatureSetPoint = 65;
#endif

  // Start bypass at 4.1V
  myConfig.BypassThresholdmV = 4100;

  //#if defined(EBMSMODULEVERSION) && (EBMSMODULEVERSION == 430 || EBMSMODULEVERSION == 420 || EBMSMODULEVERSION == 421)
  // Murata Electronics NCP18WB473J03RB = 47K ±5% 4050K ±2% 100mW 0603 NTC Thermistors RoHS
  // myConfig.Internal_BCoefficient = 4050;
  //#else
  // 4150 = B constant (25-50℃)
  // myConfig.Internal_BCoefficient = 4150;
  //#endif

  // 4150 = B constant (25-50℃)
  // myConfig.External_BCoefficient = 4150;

  // Resistance @ 25℃ = 47k, B Constant 4150, 0.20mA max current
  // Using https://www.thinksrs.com/downloads/programs/therm%20calc/ntccalibrator/ntccalculator.html
}

void watchdog()
{
  // This is the watchdog timer - something went wrong and no serial activity received in over 8 seconds
  wdt_triggered = true;
  PP.IncrementWatchdogCounter();
}

void onPacketReceived()
{
  EBMSHAL::EnableSerial0TX();

  // A data packet has just arrived, process it and forward the results to the
  // next module
  if (PP.onPacketReceived((PacketStruct *)SerialPacketReceiveBuffer))
  {
    // Only light Notification if packet is good
    EBMSHAL::NotificationLedOn();
  }

  // Send the packet (fixed length!) (even if it was invalid so controller can
  // count crc errors)
  myPacketSerial.sendBuffer(SerialPacketReceiveBuffer);

  // PLATFORM ATTINYCORE version is 1.3.2 which is old, and SERIAL.FLUSH simply
  // clears the buffer (bad)
  // Therefore we use 1.4.1 which has the correct code to wait until the buffer
  // is empty.
  EBMSHAL::FlushSerial0();

  EBMSHAL::NotificationLedOff();
}

// Kp: Determines how aggressively the PID reacts to the current amount of error
// (Proportional)
// Ki: Determines how aggressively the PID reacts to error over time (Integral)
// Kd: Determines how aggressively the PID reacts to the change in error
// (Derivative)

// 6Hz rate - number of times we call this code in Loop
// Kp, Ki, Kd, Hz, output_bits, output_signed);
// Settings for V4.00 boards with 2R2 resistors = (4.0, 0.5, 0.2, 6, 8, false);
FastPID myPID(5.0, 1.0, 0.1, 3, 8, false);

void ValidateConfiguration()
{
  if (myConfig.Calibration < 0.8 || myConfig.Calibration > 10.0)
  {
    myConfig.Calibration = 1.0;
  }

  if (myConfig.BypassTemperatureSetPoint > EBMS_MODULE_SafetyTemperatureCutoff)
  {
    myConfig.BypassTemperatureSetPoint = EBMS_MODULE_SafetyTemperatureCutoff - 10;
  }

#if defined(EBMSMODULEVERSION) && (EBMSMODULEVERSION == 420 && !defined(SWAPR19R20))
  // Keep temperature low for modules with R19 and R20 not swapped
  if (myConfig.BypassTemperatureSetPoint > 45)
  {
    myConfig.BypassTemperatureSetPoint = 45;
  }
#endif
}

void StopBalance()
{
  PP.WeAreInBypass = false;
  PP.bypassCountDown = 0;
  PP.bypassHasJustFinished = 0;
  PP.PWMSetPoint = 0;
  PP.SettingsHaveChanged = false;

  OnPulseCount = 0;
  PulsePeriod = 0;

  EBMSHAL::StopTimer1();
  EBMSHAL::DumpLoadOff();
}

void setup()
{
  // Must be first line of code
  wdt_disable();
  wdt_reset();

  // Hold flag to cater for tinyAVR2 chips
  bool just_powered_up = true;

#if defined(__AVR_ATtinyx24__)
  // Did we have a watchdog reboot?
  // The megaTinycore copies the RSTCTRL.RSTFR register into GPIOR0 on reset (watchdog, power up etc)
  // RSTFR is cleared before our code runs, so this is the only way to identify a watchdog reset
  // when using megaTinycore and tinyAVR chips.
  if ((GPIOR0 & RSTCTRL_WDRF_bm) == RSTCTRL_WDRF_bm)
  {
    watchdog();
    // Its not a power on reset, its a watchdog reset
    just_powered_up = false;
  }


/*
//Brown Out Detection
  if ((GPIOR0 & RSTCTRL_BORF_bm) == RSTCTRL_BORF_bm)
  {
    EBMSHAL::FlashNotificationLed(6, 250);
  }
*/
#endif

  EBMSHAL::SetPrescaler();

  // 8 second between watchdogs
  EBMSHAL::SetWatchdog8sec();

  // Setup IO ports
  EBMSHAL::ConfigurePorts();

  if (just_powered_up)
  {
    // 4 flashes
    EBMSHAL::PowerOn_Notification_led();
  }

  // Check if setup routine needs to be run
  if (!Settings::ReadConfigFromEEPROM((uint8_t *)&myConfig, sizeof(myConfig), EEPROM_CONFIG_ADDRESS))
  {
    DefaultConfig();
    // No need to save here as the default config will load every time if the CRC is wrong
  }

  ValidateConfiguration();

#if defined(EBMSMODULEVERSION) && EBMSMODULEVERSION < 440
  EBMSHAL::double_tap_blue_led();
#endif

  // The PID can vary between 0 and 255 (1 byte)
  myPID.setOutputRange(0, 255);

  StopBalance();

  // Set up data handler
  Serial.begin(EBMSBAUD, SERIAL_8N1);

  myPacketSerial.begin(&Serial, &onPacketReceived, sizeof(PacketStruct), SerialPacketReceiveBuffer, sizeof(SerialPacketReceiveBuffer));
}
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

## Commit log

2024-10-22 Coding full version added
    [Ebms_partitions.csv]
2024-10-22 Coding reduced version added
    [Ebms_partitions.csv]
2024-10-22 SolidWorks added. Credits: Senum
    [1-1.step.SLDASM, 1-2-75.step.SLDASM, 1.step.SLDASM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]
2024-10-22 Controller PCB Modified. Credits: Thaveesha, Nidula
    [2nd PCB.PrjPcb, 2nd PCB.xlsx, BMS.PrjPcb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]
2024-10-22 Reference. Credits: Nidula
    [BMS_Cell_Module-B_Cu.gbl, BMS_Cell_Module-B_Mask.gbs, BMS_Cell_Module-B_SilkS.gbo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]
2024-10-22 Cell PCB. Credits: Lasidu
    [2nd PCB.PrjPcb, 2nd PCB.xlsx, External Temp Sensor.SchDoc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]
2024-10-22 Remove redundant.
    [EDP_PCB.GBL, EDP_PCB.GBO, EDP_PCB.GBP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]

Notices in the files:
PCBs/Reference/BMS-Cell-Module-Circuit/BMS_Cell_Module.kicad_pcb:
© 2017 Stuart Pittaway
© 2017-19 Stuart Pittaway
